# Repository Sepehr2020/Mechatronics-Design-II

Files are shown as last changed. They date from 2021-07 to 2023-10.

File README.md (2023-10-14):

# Mechatronics-Design-II

Course Description:
Interweaves mechanisms, electronics, sensors, and control strategies with software and information technology to examine the demands and ideas of customers and find the most efficient, cost-effective method to transform their goals into successful commercial products. Most of the term is devoted to a significant design project in which student groups work independently and competitively, applying the design process to a project goal set by the faculty coordinator.

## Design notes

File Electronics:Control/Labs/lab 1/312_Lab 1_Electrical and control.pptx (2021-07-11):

## MSE 312: MECHATRONICS DESIGN II Electronics/Control Lab 1 Introduction to Simscape Electrical

Sepehr Rezvani | 301291960
Arash Pour-zargar | 301123105
Chad Graham | 301308419
Darwin Chang | 301315054

## PART B: CREATING A SIMPLE DC MOTOR MODEL

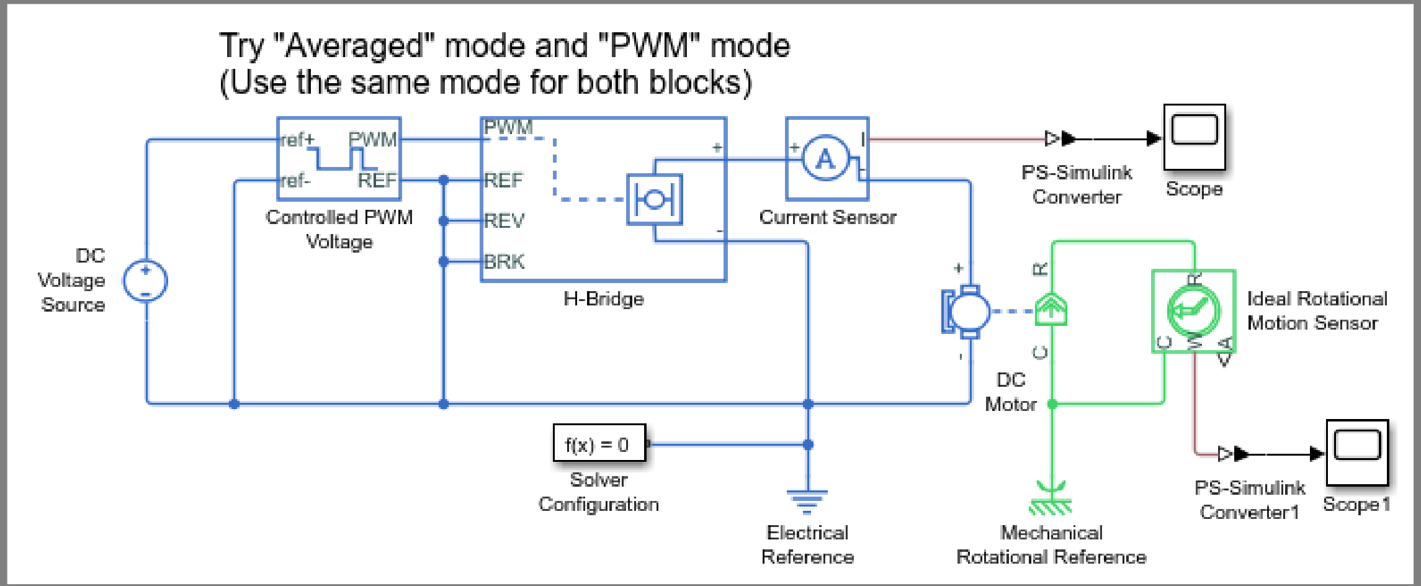
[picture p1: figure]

- Overall DC Motor Layout
- This picture was replicated in Simscape Electrical

## PART B Results

| Left | Right
Top | Averaged Current | Averaged RPM
Bottom | PWM Current | PWM RPM

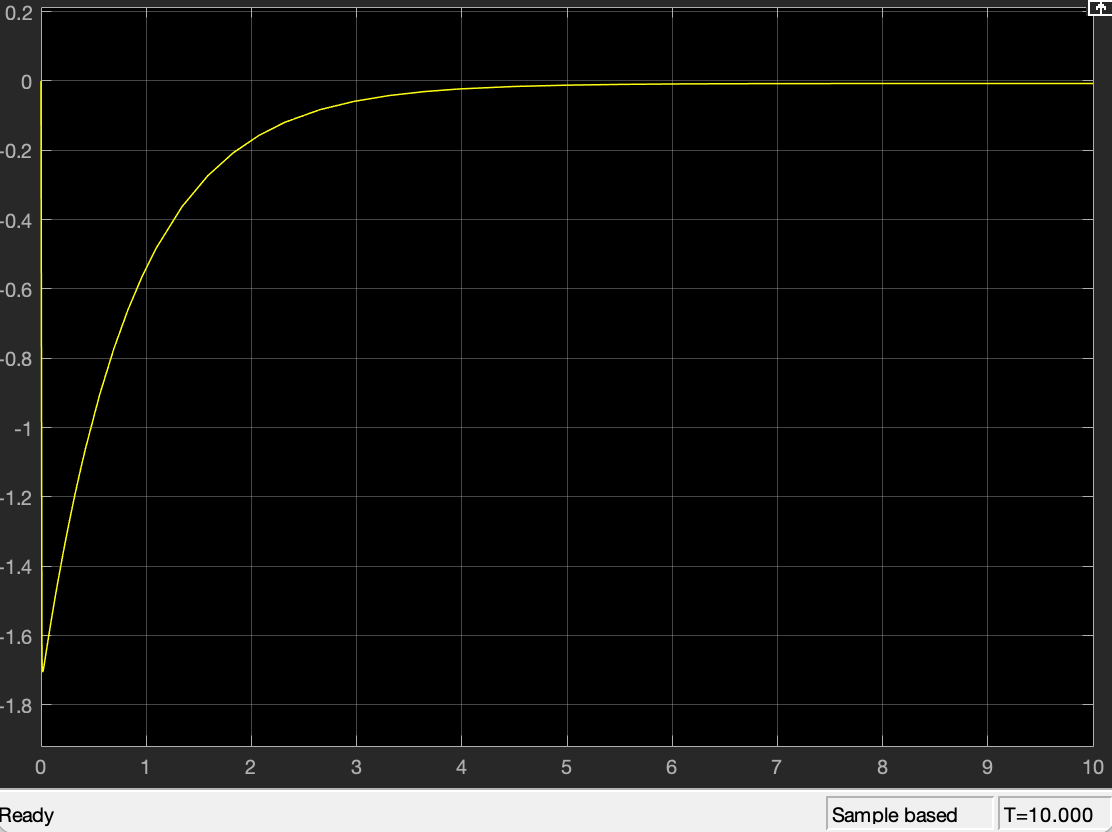
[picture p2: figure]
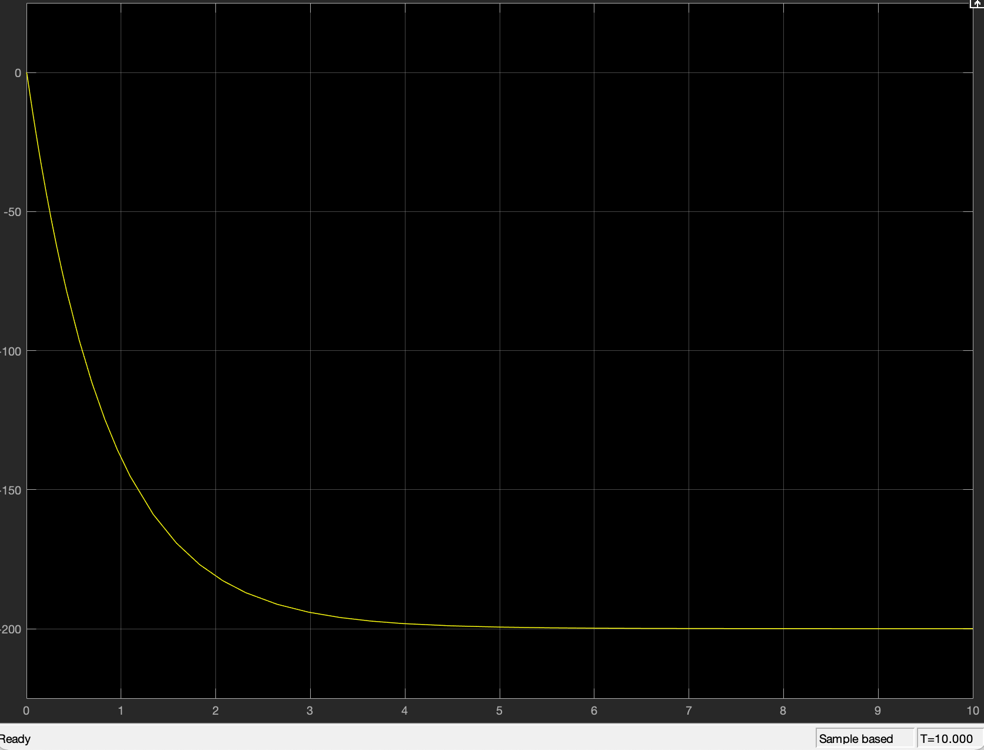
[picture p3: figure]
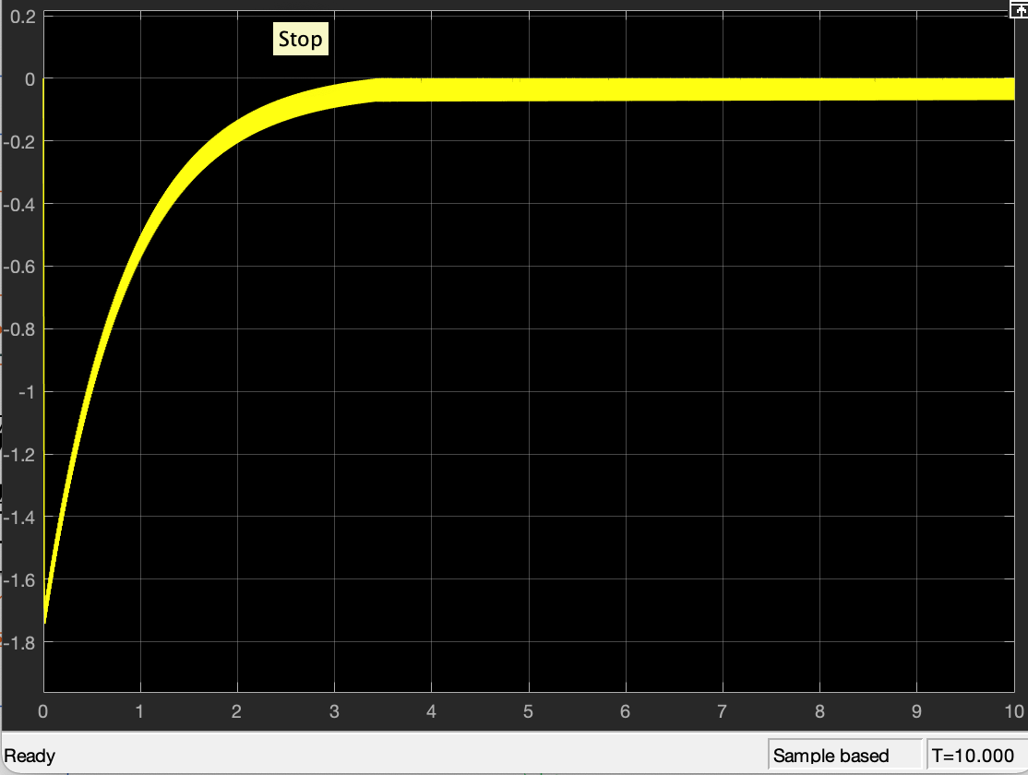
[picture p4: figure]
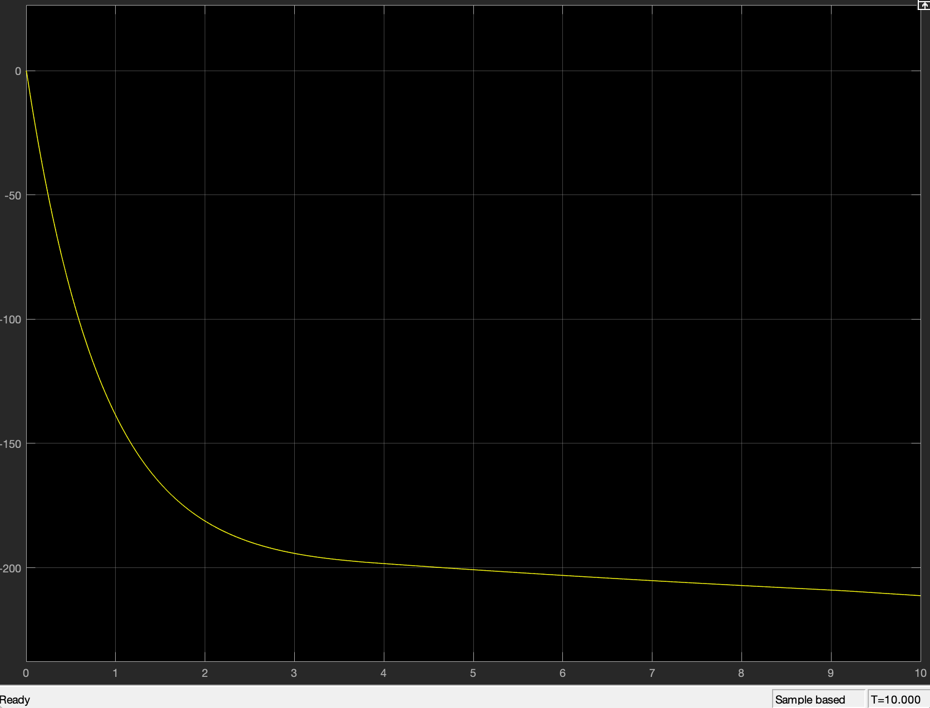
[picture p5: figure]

## ACTIVITY FOR LAB 1

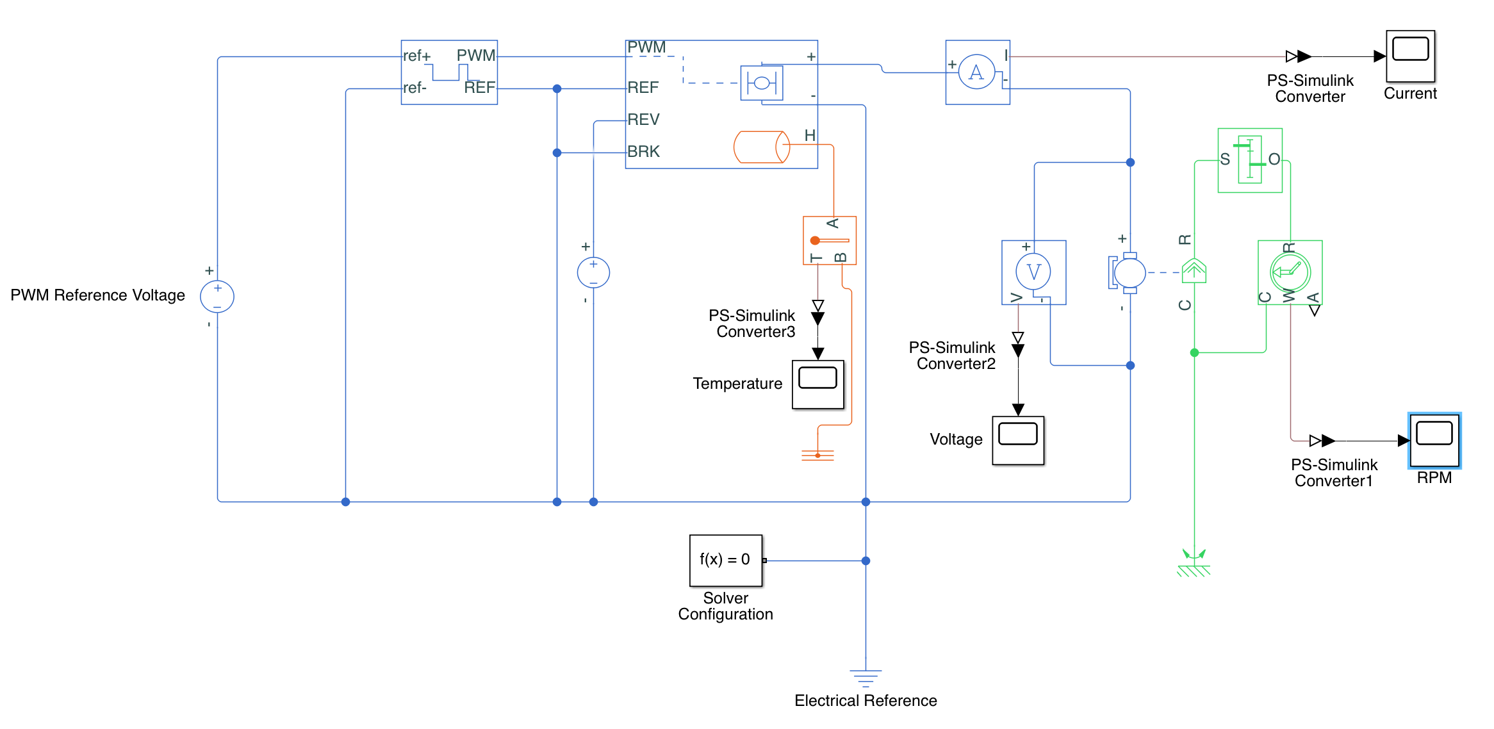
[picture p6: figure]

## ACTIVITY FOR LAB 1

- As seen on the previous page, this design is similar and based on Part B Simscape design
- Here are some additional components added and their purpose:
  - Thermal Port: The Orange section on the H-bridge → To monitor temperature of H-bridge as current goes through.
  - Temperature sensor → connected to scope from one side, and the Thermal Port from the other, to monitor temperature graph of the H-bridge as simulation completes.
  - Voltage Source: In the middle, connected to REV (on H-bridge) and ground → to change normal performance of H-bridge which acts as a diode
(AKA bidirectional requirement).
  - Gear Box → To change Speed/Torque provided by the DC motor.

## Questions

- Are our approaches correct?
  - Reversing the direction of DC Motor other than creating DC voltage source into REV Port
    - Is it possible to get it as an input signal for the REV port
  - Gearbox for Gear
    - How should we approach to measuring torque of the DC Motor
  - Is there a different way to measure power dissipation?
    - Current Method is just through temperature change in the Temperature Scope

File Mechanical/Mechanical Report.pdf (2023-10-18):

## MSE 312: Mechatronics Design II

## Summer 2021

# Project Type Selected:

# Design of a throwing arm

# Brief Mechanical Design Report

Prepared by: Long March

Students Name | Student ID
Arash Pour-zargar | 301123105
Chad Graham | 301308419
Darwin Chang | 301315054
Sepehr Rezvani | 301291960

Submission date: June 21st, 2021

Table of Contents

1 Introduction | 5
2 Design Criteria | 5
3 Proposed Concepts | 6
3.1 Design I - Tennis Ball Launcher | 6
Figure 1: Tennis Ball Launcher | 6
3.2 Design II - Catapult Arm | 7
Figure 2: Catapult Launcher | 7
3.3 Design III - Lacrosse Ball Launcher | 8
Figure 3: Lacrosse Ball Launcher | 8
4 Analytical Calculations | 9
4.2 Structural (Stiffness and Deflection) | 9
4.2.1 Design I | 9
Figure 4: Forces and geometry at the contact between the ball and the rollers during
pulling the ball in between the rollers. [1] | 9
Figure 5: Forces and geometry at the contact between the ball and the rollers [1] 10
4.2.2 Design II | 11
4.2.3 Design III | 11
Figure 6: Static study of support system generate through Solidworks simulation | 12
4.3 Dynamic (Inertia and Kinematics) | 13
4.3.1 Design I | 13
Figure 7: Projectile Motion Diagram | 13
4.3.2 Design II | 14
4.3.3 Design III | 14
5 Mechanical Design Analysis | 16
5.1 Finite Element Analysis | 16
5.1.1 Design I | 16
Figure 9: Design I Force Setup | 16
Table 10: Design I Results Summary | 16
5.1.2 Design II | 17
5.1.3 Design III | 18
Figure 12: FEA analysis Results | 19
5.2 Simulation & Validation | 20

Lab 2: Results | 20
Figure 13: Results Obtained from lab 2 | 20
6 Manufacturing | 21
6.1 Bill of Materials | 21
6.1.1 Design I | 21
Figure 14: Bill of Materials for Design I | 21
6.1.2 Design II | 22
6.1.3 Design II | 23
Figure 16: Bill of Materials for Design III | 23
6.2 Material Selection | 23
6.2.1 Design I | 23
6.2.2 Design II | 23
6.2.3 Design III | 24
6.3 Fabrication Methods | 24
6.3.1 Design I | 24
6.3.2 Design II | 24
6.3.3 Design III | 25
7 Decision Matrix | 26
8 Member Contributions | 27
9 References | 28
10 Appendices | 29
Appendix A: Analytic Calculations | 29
Kinematics of Design I: | 31
Energy Loss | 31
BOM and Cost Breakdown | 32
Design I | 32
Design III: | 37
BOM and Cost Breakdown | 38
Appendix B: Finite Element Analysis: | 39
Design I: | 39
Figure X: Design I Strain Heat map | 39
Figure X: Design I Deflection Heat Map | 40
Figure X: Design I Von Mises Stress Heat Map | 40
Figure X: Design I Force Setup | 40

Design III: | 42
Figure X: Design III Strain | 42
Figure X: Design III Safety Factor | 42
Figure X: Design III Von Mises Stress Heat Map | 43
Figure X: Design III Safety factor 2 | 43
Figure X: Design III Deflection | 43
Appendix C: Simulink/Simscape Models | 45
Appendix D: Detailed Drawing | 50
Appendix E: Lab 2 Code for Hand Calculations, Model, and Simulation | 51

### 1 Introduction

This report outlines the potential conceptual design along with the Mechanical design of a

throwing arm mechanism. Each conceptual design is analyzed and verified to investigate its

performance in its deflection, stiffness, stress, strain, and inertia. Firstly each member has developed

a couple of conceptual designs individually and then all the concepts are shared between all team

members. The pros and cons of each concept are investigated and checked by all team members to

finally come up with three potential final concepts. Finally, the selected conceptual design are

compared using a decision matrix to clarify the priority of each design in our team. The next step was

to design the selected concept using the CAD tool which in our case the software is Solidworks.

Mechanical design and detailed design in Solidworks are performed to determine detailed

information about our selected design. Some of the problems in conceptual design are improved in

this section. For example, we have improved the joint and connections in the Mechanical design to

have only one degree of freedom since it was the requirement of the project. Another example would

be decreasing the length of one of the links in order to decrease the weight of the system and have a

more optimized detailed design for this project. The next step was to determine the stress, strain, and

displacement of the arm using finite element analysis known as FEA in Solidworks .therefore we

imported the CAD model into the simulation section in Solidworks and clarified the fixed point, forces

on the arm, and a proper mesh for the arm. Then we ran the system to see the result of our

mechanical design with the specifications ball in the throwing arm system. Also, a Bill Of Material

known as BOM is added to the CAD model for the next steps in the design. Lastly, a MATLAB/Simulink

model was created for the throwing arm system to analyze the motion of the inertia and the motion

of the throwing arm system. In the following sections, we will explain all the details in a proper

sequence.

### 2 Design Criteria

For this project, our team will be focused on the functional requirements of the end product,

and non-functional aspects will have a lower priority. Our group will use a combination of

Human-Centered Design and Design Thinking. At the end of this semester, professors, who are

considered our clients, will test our products through random target locations on test day and it is imperative that the system meets the design requirements discussed in the project

description.

### 3 Proposed Concepts

3.1 Design I - Tennis Ball Launcher

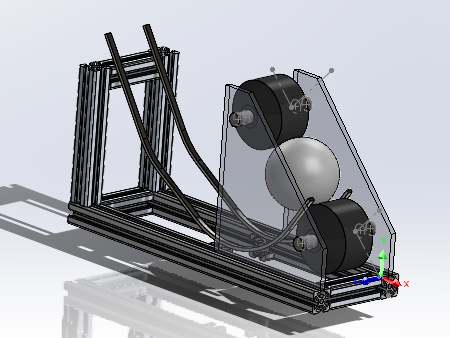
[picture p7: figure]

Figure 1: Tennis Ball Launcher

The first proposed design was a tennis ball or batting cage-style ball launcher. The system will

have the ball rolling down an inclined slope, landing in the launch area. In this area, two wheels

spinning would pull and squeeze the ball and propel it to the desired position. Due to the fixed

launch angle and start position, the only input variable that would need to change is the angular

velocity of the rollers. To protect the motor, and to increase torque a simple gearbox would be

chosen to apply the propulsion to each roller at the same angular velocity.

3.2 Design II - Catapult Arm

Figure 2: Catapult Launcher

The second proposed conceptual design was inspired by a catapult distance. This design will

have the ball at the end of the arm in a bowl-like part. The important point about this

conceptual design is that it is designed to be modular. What it means by modular is that the

middle link and the bowl part are flexible and it can be reshaped and resized in order to have an

optimized result. This conceptual design has 1 degree of freedom in the middle link to rotate

this link in a way that it can provide proper acceleration to throw the ball. The DC motor is

considered to be added at the bottom of this design and the rotary torque is transferred to the

shaft using a belt. The main reason behind that is to have the COM(Centre of Mass) of the

system as low as possible to have a stable system while throwing the ball. This mechanical

design can be controlled using an encoder for the DC motor to provide the proper angle and

acceleration for throwing the ball in order to reach the goal position. Depending on the power

and ratio that is needed in this mechanical design we can use a gearbox system to have a proper

input to the throwing arm.

3.3 Design III - Lacrosse Ball Launcher

The third design is partly inspired by the medieval trebuchet. A DC motor, represented by the

black box, is connected to the side of the throwing arm via a rope. Once the motor starts

rotating, it will pull the rope downwards, causing the arm to rotate, and launch the ball at the

end of its rotation. Similarly, another rope connects the other side of the throwing arm to the

screen door once the arm is in a vertical position (end of launch). That causes the screen door

to open and release an additional ball for the second launch. While the arm is rotating back to

its starting position after the first launch, the second ball has been released from ramp 2 and is

rolling on the ground towards ramp 1. Once the throwing arm is back on the ground to the start

position, the ball will backward from ramp 1 and fall at the end of the throwing arm.

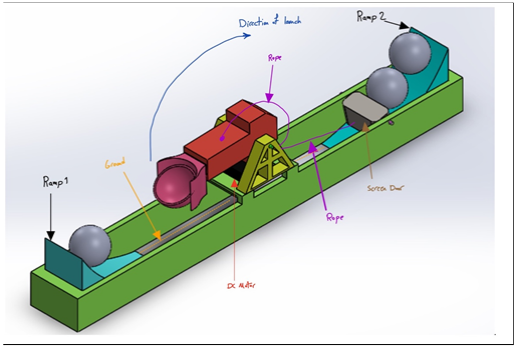
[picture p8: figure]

Figure 3: Lacrosse Ball Launcher

### 4 Analytical Calculations

4.2 Structural (Stiffness and Deflection)

4.2.1 Design I

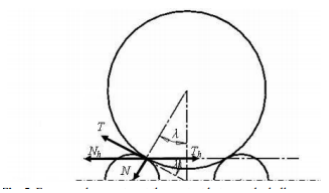
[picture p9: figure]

Figure 4: Forces and geometry at the contact between the ball and the rollers during pulling

the ball in between the rollers. [1]

When the ball is being pulled by the rollers, two main forces appear at the contact points

between the ball and the rollers. These are: the pressure force ‘N’, which is normal to the

contact surface, and the tangent friction force ‘T’ [1].

The relationship between the pressure force and the friction force is proportional to the

coefficient of friction between the materials. This coefficient will be taken from online resources

for approximate materials.

T = µ · N

Figure 5: Forces and geometry at the contact between the ball and the rollers [1]

The condition for throwing the ball away from between the rollers states that the friction force

between the ball and the rollers should be equal or greater than the inertia force of the ball.

The pressure force can be obtained from the definition of Young’s modulus for the ball:

N =

E·s·∆l
2r
Where ‘s’ is the contact area of the ball under compression. The pressure force and tangent

force were determined to be 113.1N and 82.56N respectively. See Appendix A for calculations.

Thus the maximum external load on the system is 113.1N distributed onto the drive shaft. This

force will be used for bending moment calculations performed on the motor drive shaft to

ensure it is within the specifications.

4.2.2 Design II

The first step in static analysis is to have FBD of the system therefore we have added FBD of our

system in the Appendix with all forces on the throwing arm. Then we have used a second

Newton’s law to calculate forces in the joint.

4.2.3 Design III

Two “Arm_support” parts as shown in the following figure must balance out forces and

moments against the rotating arm. Static equations, free body diagrams and detailed

calculations of results

are included in Appendix A.

Figure 6: Static study of support system generate through Solidworks simulation

4.3 Dynamic (Inertia and Kinematics)

4.3.1 Design I

The system will consider the start position of the ball to be between the two rollers at a fixed

angle of 45 degrees to optimize trajectory. The input into the plant will be the angular velocity

of the rollers.

During the throw, the ball takes some energy from the rollers while going through them. This

decreases the rotational speeds of the rollers. To analyze this further we must consider the

kinetic energy of the rollers at the time of the ball being thrown. We came to the conclusion

that the initial angular velocity must be adjusted to the following. See Appendix A for the

breakdown.

ω0 = ω +

1
2

I

ballω

2

Now that the input has been determined, the landing position of the ball can be determined

using standard projectile motion calculations.

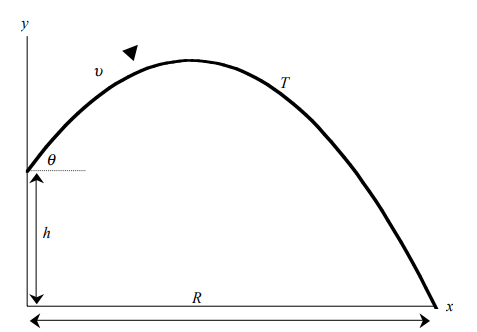
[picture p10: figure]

Figure 7: Projectile Motion Diagram

4.3.2 Design II

The second step is to calculate the moment of inertia for the arm using the following equation

Then we would be able to calculate all the Mechanical design parameters which are added in a

table in the appendix.

For the other part which is the base of the catapult design we only need a static analysis to

make sure the base will be stable during the throwing period using the following equation. The

corresponding image is added in the appendix

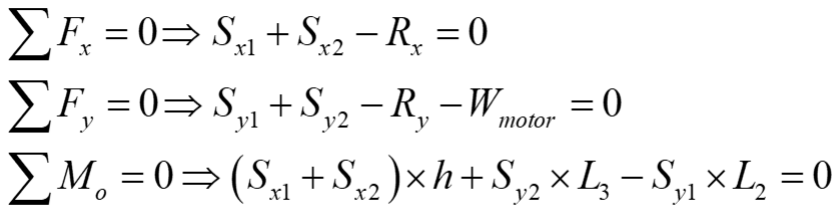
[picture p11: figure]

4.3.3 Design III

As shown in the following figure, the Throwing arm’s center of mass is away from the rotating

rod. Therefore, to balance forces and moments acting on the supports, the arm must be

designed in a way that is more dense on the right (in red). The reason for this design is to

balance negative torque, help with rotations counter torque, and minimize the power required

from the DC motor.

Figure 8: Mass distribution of the arm

This logic can also be seen in trebuchet design in the following figure. Instead of m1 in

trebuchet, our design is denser on the right side.

### 5 Mechanical Design Analysis

5.1 Finite Element Analysis

5.1.1 Design I

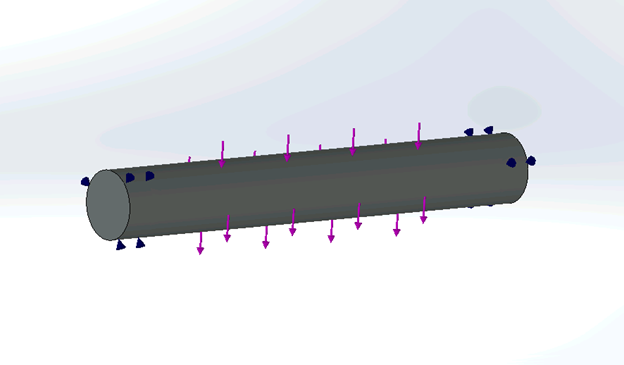
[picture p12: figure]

Figure 9: Design I Force Setup

A FEA analysis was performed on the drive shaft of the proposed tennis ball launcher concept

and the heat maps can be found in Appendix B. Bearing fixtures were set up on the edge of

each shaft to imitate its final design. The force was applied perpendicular to the axis of the shaft

to mimic the friction force applied from the ball. The summary table can be seen below.

Table 10: Design I Results Summary

Parameter | Simulated Results | Analytical Solution
Displacement/Deflection | 0.9104mm | 1.66mm
Yield Strength | 2.206x10^8 Pa | N/A
Strain | 3.401 x 10^-04 | N/A

The analytical and simulated results were comparable for the deflection of the drive shaft as

shown in the table above. The next following section will discuss material selection to ensure

the concept will perform as intended.

5.1.2 Design II

For the finite element analysis, I have imported the CAD model into the simulation section of

the Solidworks in order to analyze displacement, stress, and strain of the throwing arm to make

sure the throwing arm can tolerate the weight of the ball and other forces on it. Thus the results

are added below

Figure 11a: FEA of the beam

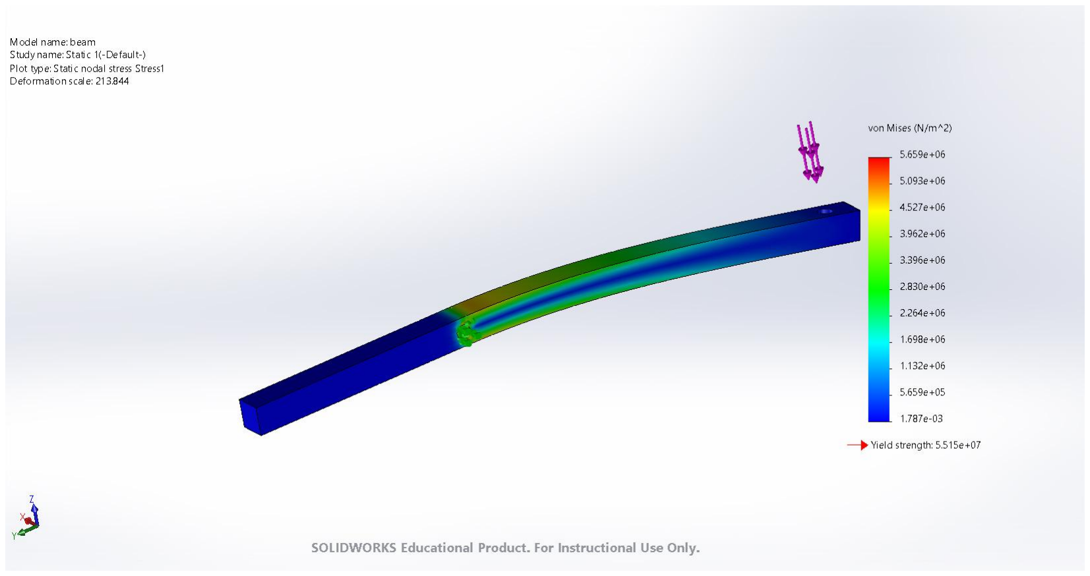
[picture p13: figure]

Figure 11b: FEA of the beam

5.1.3 Design III

After performing FEA analysis in Solidworks for this design, results for stress, deflection, and

strain are calculated and presented in the following table. For a more detailed analysis of figures

refer to Appendix B under “Design III”.

Name | Type | Min | Max
Stress | VON: von Mises Stress | 6.425e+00N/m^2 | 4.204e+04N/m^2
Displacement | URES: Resultant Displacement | 0.000e+00mm | 1.308e-05mm
Strain | ESTRN: Equivalent Strain | 2.640e-10 | 2.620e-07
Factor of Safety1 | Max von Mises Stress | 1.927e+04 | 1.261e+08
Factor of Safety2 | Max von Mises Stress | 1.927e+04 | 1.261e+08

Figure 12: FEA analysis Results

5.2 Simulation & Validation

Assembly files from three designs were exported into Matlab Simscape. Simscape helps with

developing physical models and simulate them. Results from the second lab are presented in

the following table. In addition, codes and figures of our Simscape designs are included in

Appendix D.

Lab 2: Results

| Angular Velocity (After 10 second) | Angular Acceleration (After 10 seconds)
Base Model | -4.53811 | -10.3749
Geometry 2 | 4.7461 | 9.0776
Geometry 3 | -4.5887 | -10.1299
Material (rho) 2 | 4.6073 | 9.9035
Material (rho) 3 | 4.516 | 10.4963
Inertia 3 | 0.7689 | 0.0415
Solver (auto) | 4.5023 | 10.5475
Solver (ode15s and time 0.001s) | 4.5023 | 0.5475
Damping (8e-4) | 4.8418 | 7.8544
Damping(8e-1) | -4.45E-04 | 9.93E-05
Torque (100) | 23.2331 | -15.7428
Torque (1) | 4.4613 | 10.675

Figure 13: Results Obtained from lab 2

### 6 Manufacturing

6.1 Bill of Materials

6.1.1 Design I

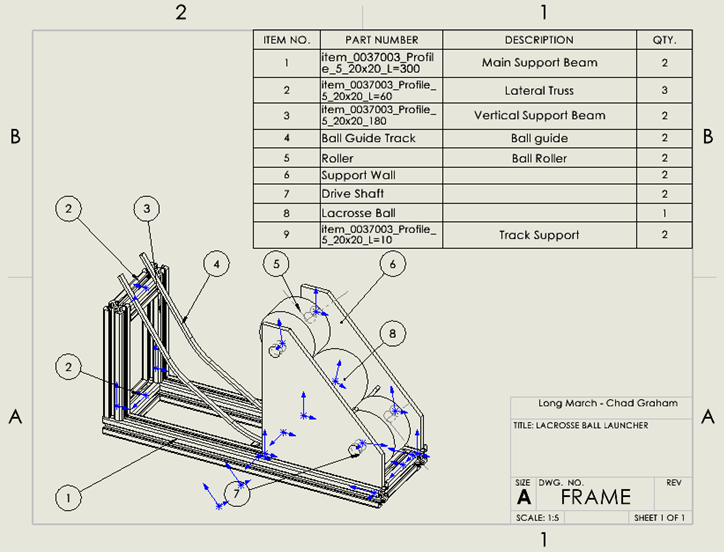
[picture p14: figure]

Figure 14: Bill of Materials for Design I

6.1.2 Design II

Figure 15: Bill of Materials of Catapult Arm

6.1.3 Design II

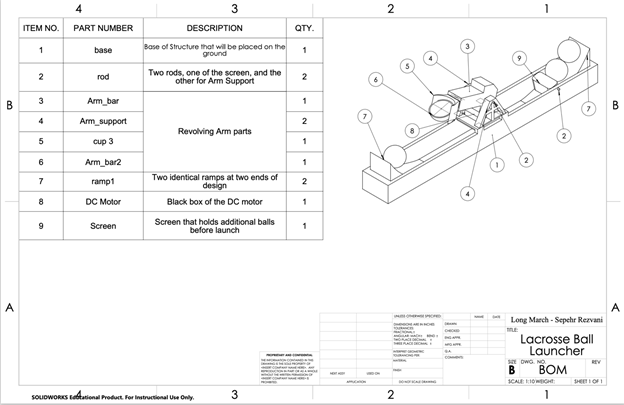
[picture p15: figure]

Figure 16: Bill of Materials for Design III

6.2 Material Selection

6.2.1 Design I

The main structure will be constructed from aluminum extrusion due to its incredible yield

strength, availability, and affordability. The Ball Guide Track is made out of stainless steel. The

driveshaft was selected to be made out of 1045 Cold Drawn Steel due to its corrosion resistance

and superior yield strength. The rollers will be made out of high-density rubber to maintain a

high coefficient of friction with the lacrosse ball to minimize slip.

6.2.2 Design II

There are many choices for selecting the proper material for the components of the second

design. First of all, we have tried to use one material for the whole system in order to reduce the cost of manufacturing and maintenance of the throwing arm project. Thus using static

analysis results which are added in the appendix we have decided to use aluminum alloy 6061

as the main material for manufacturing the second design. The approximate cost of the design

according to the quantity of the material used is around $200-$250 dollars

6.2.3 Design III

As shown in table (Design III) in Appendix A under "BOM and Cost Breakdown", the materials

selected are based on the purpose of parts in the design. For example, “Titanium Ti-8Mn,

Annealed” is used for the “Arm_support” part due to the high stress applied to this part. For

other parts like ramps, where very little load is applied, simpler and cheaper materials were

selected. Another factor considered for the material selected is their availability in the

Solidworks database, in some special instances, better materials could be selected if they were

available in Solidworks.

6.3 Fabrication Methods

6.3.1 Design I

This iteration was purposely designed for ease of manufacturing in mind. Each material is

readily available from local suppliers such as Proax, McMaster Carr, and others. Basic hand tools

will be used to fabricate the simple frame structure and the drive shaft can be ordered from

McMaster Carr to fit the design. Extrusion can be cut with a simple saw and constructed with

nuts and bolts.

6.3.2 Design II

Depending on the material that we select for the second design we have different options for

manufacturing the components for example if the material is selected to be PLA then the

manufacturing method would be 3D printing. For this project if the material is aluminium alloy

the manufacturing method is selected to be CNC machining however we have an option to

move forward with 3D printing method for the Cap in the second design thus since the shape of

this component would cost more using CNC machining

6.3.3 Design III

As mentioned in the previous section, materials were selected based on their importance and

cost. Referring to Appendix A, these main portions of our budget would be allocated to the

main arm and its supports. All materials are available and can be purchased with our limited

budget.

### 7 Decision Matrix

A weighted objective chart (WOC ) is used as a means of comparing various alternatives by

ranking them based on a list of criteria . The weighted table work is that the user pre-rank the

important stuff each of the comparison criteria in advance then ranks each design option based

on how well it fulfills each of the criteria. The list of criteria for our project is shown below:

In the following, different values are assigned to each score so that the higher score has a better

advantage to our design for example if the cost of the design is less then its score would be

higher. The list of criteria with the corresponding values is shown below.

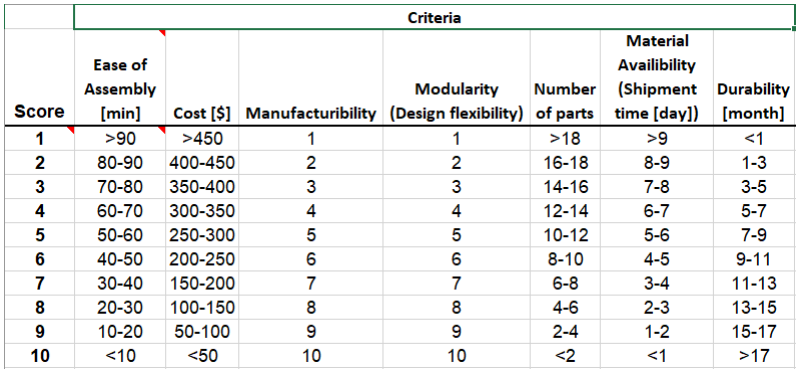
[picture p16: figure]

Figure 17: Decision Matrix

Finally, the criteria and the corresponding score are finalized and now we have assigned a

weight to each criterion .it should be noted that the total weight should be 100%. Then we have

compared all three concepts using a score for each criterion and added a value

(is equal to score *weight ) for each criteria. Finally, the accumulated values are compared in

the following table

Figure 18: Selected Design

Ultimately this led our team to select Design III as our mechanical concept. It yielded the

highest overall score by a significant amount. Though selected, the design will continue to be

iterated and optimized to properly integrate the motor and drive system.

### 8 Member Contributions

Chad Graham - Design I (Mechanical design, analytical calculations, FEA, BOM, material

selection, cost breakdown. report, etc.), report format layout, grammar correction, and

organization.

Arash Pour-Zargar- completed design 2 on the FBD design as well as FEA, material selection,

BOM, and creation of the report template as well as the decision matrix

Sepehr Rezvani - Design III and report+formatting: Including Solidworks parts, drawings, and

one final assembly file. FEA was done on Throwing Arm support, BOM and final cost estimation

was completed as well.

Darwin Chang - Report. Ensuring compatibility and Importing of the Solidworks model into the

Simulink/simscape models to be able to create the Model for the three designs. Simulated the models and fixed model errors present in the importing process. Obtained the results for Lab 2

shown in appendices E. Report Grammar, and Formatting

### 9 References

[1] K. WÓJCICKI, K. PUCIŁOWSKI, and Z. KULESZA, “Mathematical Analysis for a New Tennis Ball

Launcher,” Acta Mechanica et Automatica, vol. 5, no. 4, pp. 110–119, 2011.

[2] | “Polymer | Properties | Database,” | Rubber | Elasticity. | [Online]. | Available:
https://polymerdatabase.com/polymer%20physics/RubberElasticity.html. | [Accessed:

20-Jun-2021].

3] K. WÓJCICKI, K. PUCIŁOWSKI, and Z. KULESZA, “Mathematical Analysis for a New Tennis Ball

Launcher,” Acta Mechanica et Automatica, vol. 5, no. 4, pp. 110–119, 2011.

L. L. C. Engineers Edge, “Coefficient of Friction Equation and Table Chart - Engineers Edge,”
Engineersedge.com. | [Online]. | Available:

https://www.engineersedge.com/coeffients_of_friction.htm. [Accessed: 20-Jun-2021].

“Polymer | Properties | Database,” | Rubber | Elasticity. | [Online]. | Available:
https://polymerdatabase.com/polymer%20physics/RubberElasticity.html. | [Accessed:

20-Jun-2021].

### 10 Appendices

Appendix A: Analytic Calculations

Load Validation Design I:

N =

E·s·∆l
2r =

(4.0×10

6
Pa)( 5.94×10

−4m

2
)(0.003m)
2·(0.0315m) | = 113. 1N

S = Contact area during deformation
s = 2 · π · r · ℎ = 2 · π · (0. 0315m) · (0. 030m) = 5. 94 × 10⁻⁴
m

2

The area of deformation was determined by considering the surface area of a dome with the

height equal to one half of the deformation height (3mm).

△l = deformation height

The deformation height is determined from the spacing between the two rollers. The rollers

were separated by the diameter of the ball minus 6 mm to ensure a constant pressure is

maintained.

R = radius of the ball

E = Young’s Modulus

Since the material of a lacrosse ball is not consistent, vulcanized rubber (a common component

in lacrosse balls) was selected to represent the material properties. 4.0MPa was determined for

our calculations[CHAD 2].

The coefficient of friction was found from an online resource to be 0.73[CHAD 3].

T = µ · N = (0. 73)(113. 1N) = 82. 561N

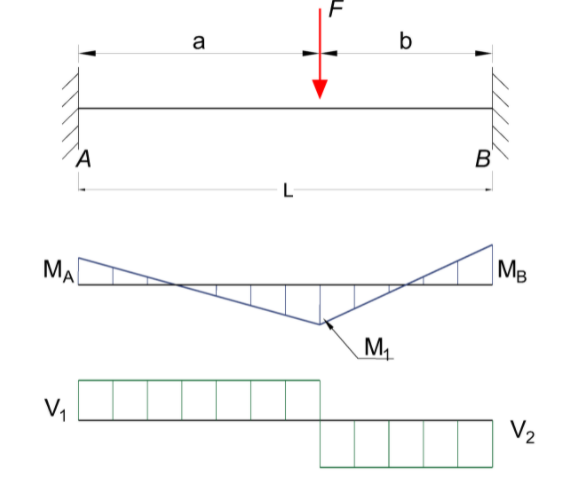
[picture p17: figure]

Figure 19: Bending Moments Graph

The moment of the fixed ends of the beam was determined as follows.

M

A = M

B =

−Fa

3

L

2 =

(113N)(0.0426)

3

(0.0852)

2 = 0. 00120345Nm

The moment of the center of the beam was determined as follows.

M =

2·F·a
L

3 =

2·(113)(0.0426)
(0.0852)

3 = 1. 20345×10 − 5Nm

The deflection was calculated for the top of the shaft at its extremity as follows.

δ

beam =

F·a

6

3·L

3
·E·I

= 1. 66311386×10 − 4m

Kinematics of Design I:

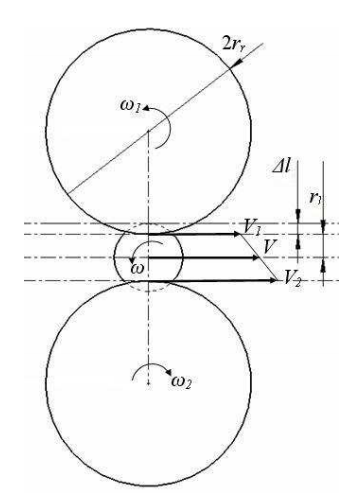
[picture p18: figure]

Figure 20: Tennis Ball Launcher Cross Section

V =

V

1 +V
2
2 ϖ · r

roller =

V

2−V
1
2

V =

(ω1+ω2

)·r

2

Energy Loss

Consider the kinetic energy of the rollers at the moment the ball is thrown.

∆E = E

1 − E

2 =

1
2
- I
roller

[(ω1

2
+ ω2

2
) − (ω10

2
+ ω20

2
)]
Where; | I

roller =

1
2 mr

2

For the ball it can be assumed that its initial kinetic energy is zero, while the final energy, in this

case immediately after the throw, depends on its linear and rotational speeds of the rollers.

Since both rollers will have the same angular velocity the angular velocity of the ball can be

assumed to be zero.

Thus; | ∆E =

1
2
- mV

2
+

1
2

I

ballω

2

Where; | I

ball =

2
3 mr

2

Therefore the initial kinetic energy of the plant required to launch the ball using the equations

above can be shown as:

E =

1
2

I
roller

(ω1

2
+ ω2

2
) +

1
2 mV

2
+

1
2

I
ball
Making the assumption that angular velocity before and after the launch are the same:

ω10

ω20

≃

ω1

ω2

Then, the initial rotational speeds of the rollers, needed to throw the ball with the required

linear and rotational velocities can be calculated, as:

ω0 = ω +

1
2

I

ballω

2

BOM and Cost Breakdown

Figure 21: Cost Breakdown of Tennis Ball Launcher

Design I

Design III:

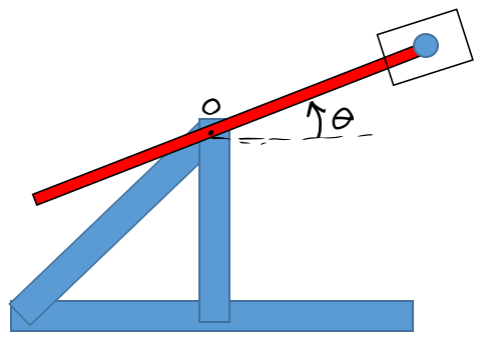
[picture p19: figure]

Figure 22: Cross Section of Catapult

The first step for static analysis is to have FBD of the Catapult throwing mechanism. I have

added the FBD as follows

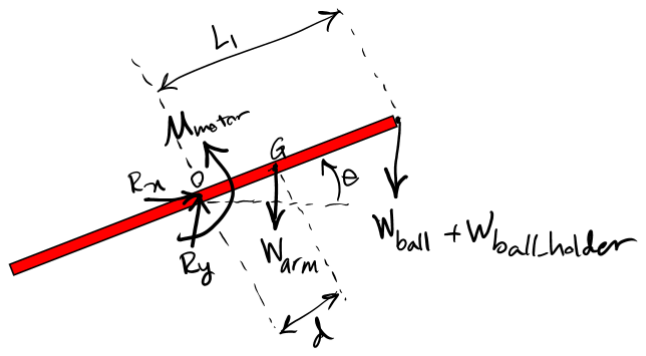
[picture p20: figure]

Figure 23: FBD Diagram of throwing mecahnism

Figure 24: FBD fo the A frame

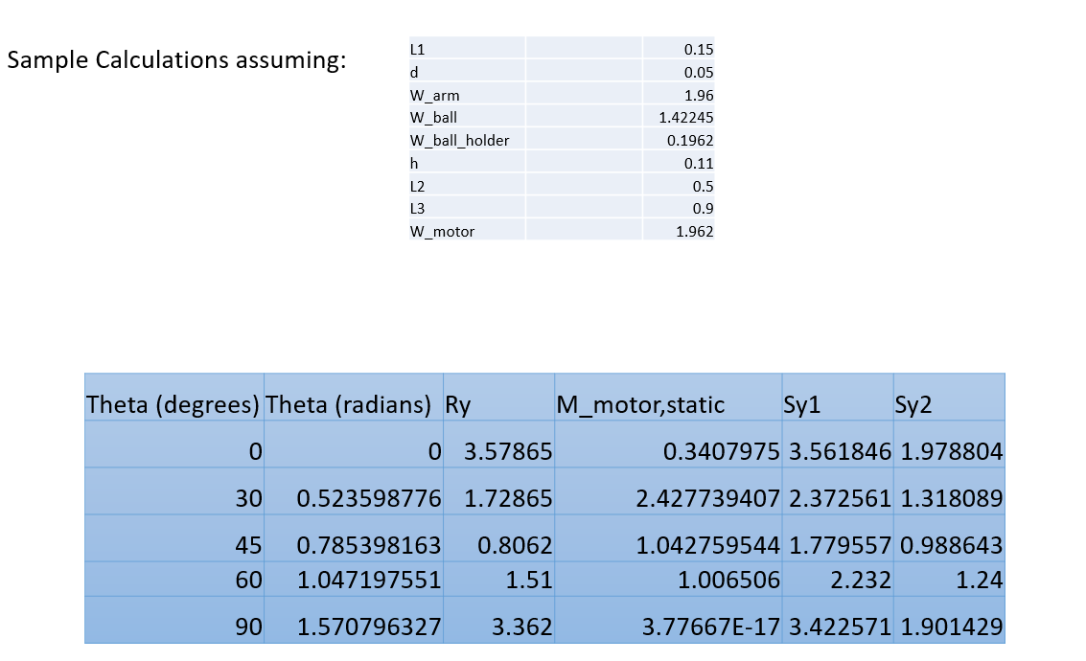
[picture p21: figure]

Figure 25: Sample Calculations

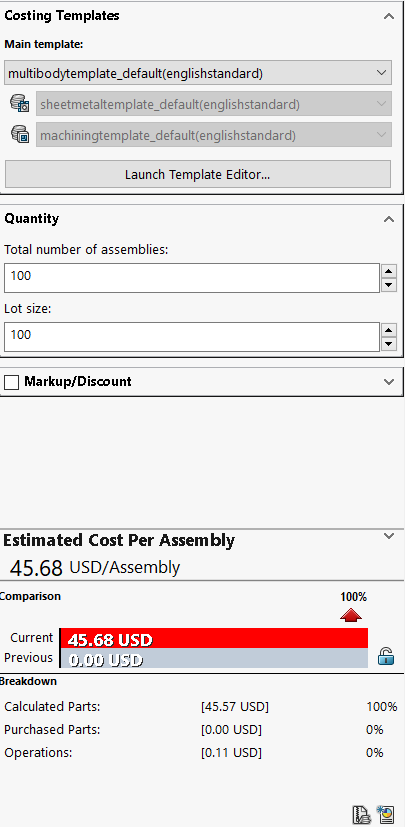
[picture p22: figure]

Figure 26: Cost Breakdown of Catapult System

Design III:

Figure 27: FBD and calculations of Design 3

BOM and Cost Breakdown

Appendix B: Finite Element Analysis:

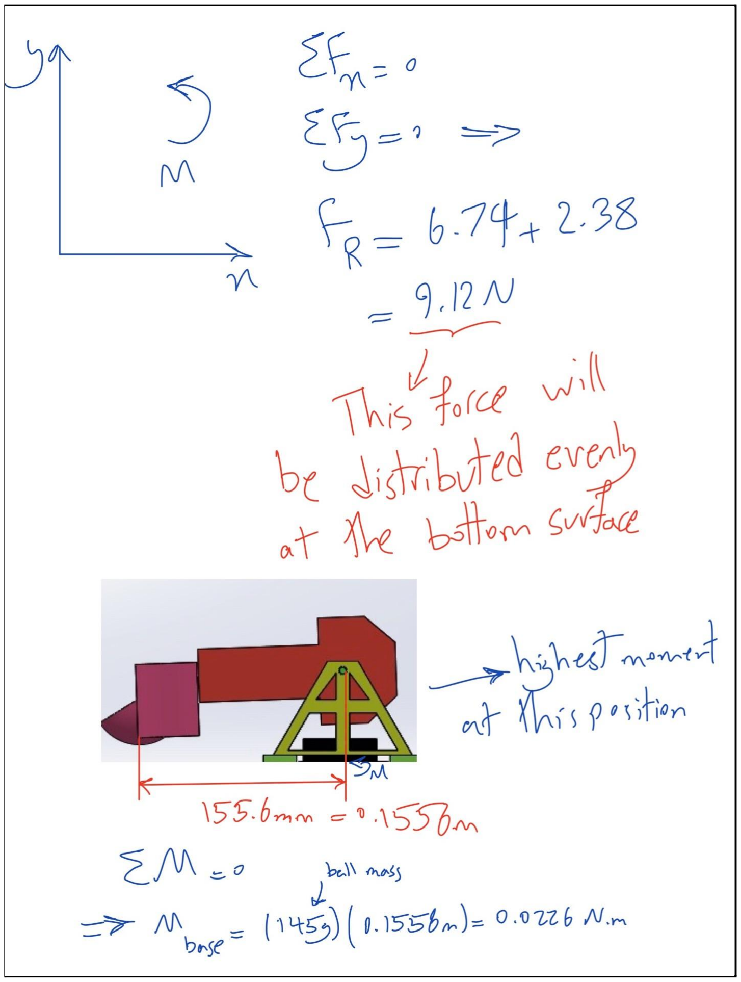
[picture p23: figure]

Figure 27: FBD and calculations of Design 3 cont.

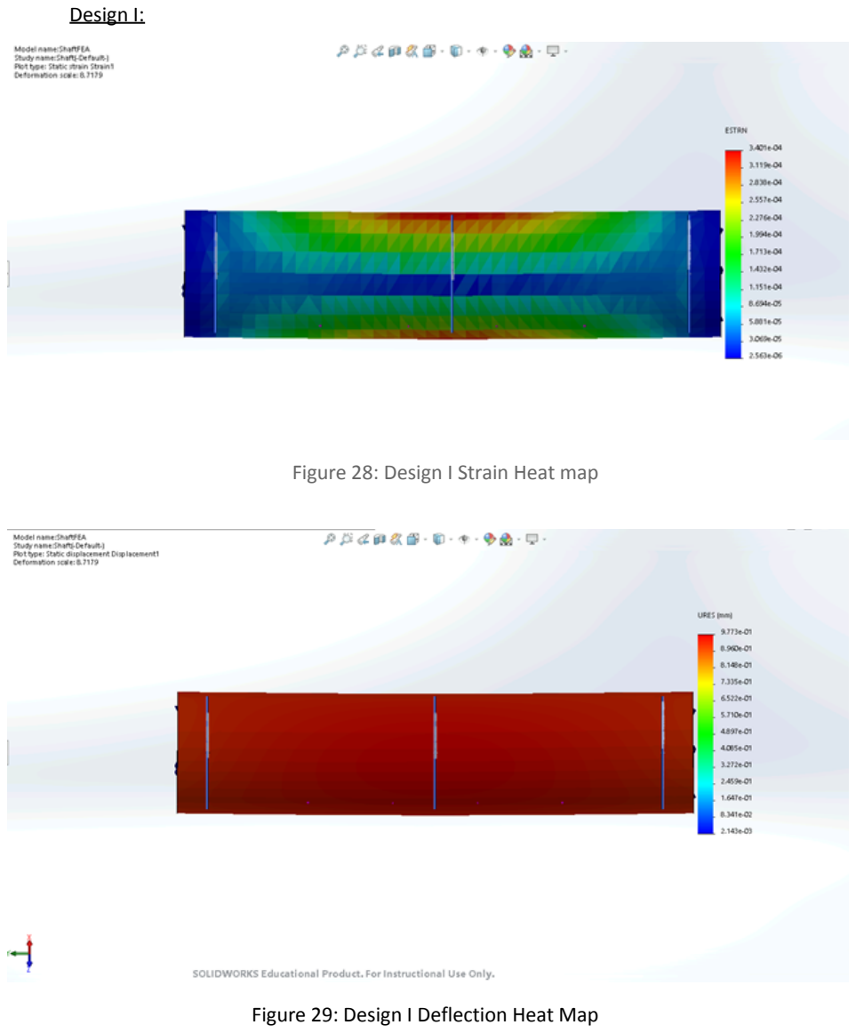
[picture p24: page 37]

Design I:

Figure 28: Design I Strain Heat map

Figure 29: Design I Deflection Heat Map

Figure 30: Design I Von Mises Stress Heat Map

Figure 31: Design I Force Setup

Design III:


Figure 32: Design III Strain

Figure 33: Design III Safety Factor


Figure 34: Design III Von Mises Stress Heat Map

Figure 35: Design III Safety factor 2

Figure 36: Design III Deflection


Appendix C: Simulink/Simscape Models

Model 1:

Figure 37: Simulink Model for Design 1: Tennis Ball Launcher

Model 2: Catapult Arm

Figure 38: Simulink Model for Design 2: Catapult Launcher

Model 3:


Figure 39: Simulink Model for Design 3: Lacrosse Ball Launcher

Appendix D: Detailed Drawing


Figure 40 - Drawing of Design III Assembly Signed by Group Members

Appendix E: Lab 2 Code for Hand Calculations, Model, and Simulation

close all

clc

% Calculations for lab 2

rho = 2700;

length=1;

width=0.10;

thickness=0.10;

volume = length * width * thickness;

mass = rho * volume;

inertia_cent = (1/12)*(length^2 * width^2);

inertia = inertia_cent + (mass)*(length/2)^2;

% assumming start from rest, and bar is horizontal

gravity = 9.81;

energy=mass*gravity*sin(pi/2)*length;

velocity = sqrt((energy*2)/mass); %from kinematic energy

ang_velocity_90=velocity*length/2;

disp(ang_velocity_90)

ang_velocity_180=0; % returns to starting height

disp(ang_velocity_180)

ang_velocity_270=-ang_velocity_90; % same as 90 but opposite direction

disp(ang_velocity_270)

ang_velocity_360=0; % back to original direciton

disp(ang_velocity_360)

figure;

hold on;

plot(out.w);

plot(out.a);

legend('w', 'a')

disp(out.w(end));

disp(out.a(end));

Figure 41: Code for Lab 2 Calculations


Figure 42: Simulink Model for Lab 2, pendulum arm

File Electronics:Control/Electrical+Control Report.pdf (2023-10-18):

## MSE 312: Mechatronics Design II

Summer 2021

# Electronic Drive Circuit and Control System Design for a Throwing Robotic Arm:

### Prepared by: Long March

### Submission Date: July 25th

, 2021

Student Name | Student ID
Sepehr Rezvani | 301291960
Chad Graham | 301308419
Arash Pour-zargar | 301123105
Darwin Chang | 301315054

Table of Contents

### Introduction

In this project we develop controllers for a Throwing Robotic Arm, which throws a ball from a

reference point (zero position) to a target point. The target point is in three different ranges,

and the ball must land withing 2cm of the specified location.

In Mechanical portion of this course, Long March developed three mechanical designs in

Solidworks, and integrated them in Simulink for simulation. Once mechanical part the project

was completed, Long March has been focused on designing power electronics drive circuitry for

our electronic system. Additionally, simulations at different levels have been completed as well

in order to validate quality of our electronic system.

While some members have been working on electronics design, other have been working on

the control portion of the project as well. The DC motor (GM8724S009), H-Bridge (TB6568KQ)

and other electronics components power the mechanical side of the design. However, control

circuitry is as important as the power systems since the motion of the Throwing Arm must be

fully controlled. Otherwise, the ball cannot successfully leave the arm.

In this report, Long March will demonstrate how to design, test, and validate electronics and

control components of this course. Readers can follow report’s instruction to simulate a similar

project in Matlab/Simulink.

## Part A: Electronics

Electronics Introduction

In this section the design and power interface circuitry for driving a DC motor carrying an

inertial load, in this application our throwing arm. In a real system, a power electronics

interface is necessary since the control/command signals from the microcontroller cannot

provide enough power to drive the motor and the electromagnet.

Motor Selection

Seeing as the desired system is to be electro-mechanical, a suitable motor is to be selected to

propel our ball to its destination. The following criteria will be used to select our motor.

- Must be a DC Brushed motor capable of forward and reverse actuation
- Must be within the 0-12VDC operating range to minimize power
- Must be capable of generating at least 6.004oz*in of torque as calculated to be the

minimum torque to drive our mechanical system.

- Must have a gearbox to reduce strain on motor and increase torque
- Gearbox must be of at least 90% efficiency to minimize power loss.
- Must be affordable to be within project budget.

Figure 1: GM8724S009 DC Gearmotor [1]

The following motor was selected for our system. The GM8724S009 DC servo gear motor is a

DC motor made with Copper-Graphite brushes that has a nominal voltage of 12VDC. It’s gear

ratio of 6.3 and stainless-steel shaft will reduce strain on the motor and provide up to 42 oz*in

of torque to our system [1].


Figure 2: GM8724S009 Torque Speed diagram

In the figure above the vertical green line represents the minimum torque needed to propel the

ball in our system. It is clear it is well within the operating range of our system and still provides

a lot of operating power to propel the ball to the desired positions.

Design Stages of Power Electronics Drive Circuitry

DC Motor Control

Theory

A simple DC motor uses a stationary set of magnets in the stator, and a coil of wire with a

current running through it to generate an electromagnetic field aligned with the center of the

coil. One or more windings of insulated wire are wrapped around the core of the motor to

concentrate the magnetic field.

The windings of insulated wire are connected to a commutator (a rotary electrical switch), that

applies an electrical current to the windings. The commutator allows each armature coil to be

energized in turn, creating a steady rotating force (known as torque) [2].

By nature, applying a positive voltage potential across a motor will rotate the motor forward

and applying a negative voltage potential across the motor will rotate the motor in reverse.

Thus, it is imperative to design a controller that can convert simple control signals into the

desired direction control.


Figure 3: Direction Control of a DC motor

The proposed electrical circuit is a H-Bridge circuit. In general, an H-bridge is a rather simple

circuit, containing four switching elements, with the load at the center, in an H-like

configuration:


Figure 4: H-Bridge Circuit Topology

The switching elements (Q1...Q4) are usually bi-polar or FET transistors, for our application we

are using MOSFETs. The diodes (D1...D4) are called kick-back or snubber diodes. The top-end of

the bridge is connected to a power supply (battery for example) and the bottom-end is

grounded. The operation table can be seen below according to Figure 5.

Table 1: H-Bridge Sequence

Motor Operation | S1 | S2 | S3 | S4
Off | Open | Open | Open | Open
Clockwise | Closed | Open | Open | Closed
Counter-clockwise | Open | Closed | Closed | Open
Invalid | Closed | Closed | Closed | Closed


Figure 5: H-Bridge Circuit

The speed can be controlled using PWM. Changing (modulating) the width of the pulse applied

to the motor can increase/decrease the amount of power provided increasing/decreasing the

motor speed.


Figure 6: PWM Diagram

Implementation

A Toshiba TB6568KQ Full-Bridge DC Motor Driver IC was selected to be our H-Bridge device. The

basic electrical implementation in Simulink can be shown below. This model shows how to use the Controlled PWM Voltage and H-Bridge blocks to control a motor. The DC Motor block uses

manufacturer datasheet parameters found on our H-Bridge and motor datasheets respectively.


Figure 7: Electrical Control Simulink Circuit

To implement direction control, the H-Bridge block by default runs in the forward direction and

if the voltage applied at the ‘REV’ port is larger than a pre-defined voltage, the motor will run in

reverse. Thus, if the voltage is greater than zero volts, 5V is applied to the ‘REV’ port and the

motor is ran CW, if it is less than 5V, 0V is applied to the ‘REV’ port and the motor is turned

CCW.

Figure 8: Simulink Circuit of Direction Control

The simulation was populated with the parameters obtained from the respective datasheet.

This can be found in Appendix: Part A. The simulation results can be found in the sections

below.

Thermal Design for PWM Chip

Using the properties from the TB6568KQ datasheet [4] the selection criteria for a heatsink can

be obtained. The temperature difference between the junction and the ambient depends on

the power dissipation (PD) and the thermal resistance between them as shown in the equation

below. The PD was extracted from the datasheet to be 7.80W. Seeing as the power dissipated

was less than 10W, a passive heatsink was selected.

The thermal resistance between the Chip and the Ambience can be broken down into a pair of

series resistances as shown below.

Combining the two equations listed above and rearranging to solve for the unknown thermal

resistance of the Chip to the Case can be shown as follows where θChipCase was extracted from

the datasheet to be 6°C/W. TChip is a known value for silicon devices to be 150°C.

A rough formula for designing a passive heat sink can be shown below where the area units are

in cm² and the thermal resistance is measured in °C/W.

Applying a 50% safety factory yields an aluminum heat sink area of 37.5cm² .

Simulation Results for Evaluation Power Drive Circuit Operation

Long March has implemented lab 1 design in the project. Many factors such as nonlinearities

and uncertainties from the electrical section can affect the performance of the system. This

section explains how different parameters (e.g. motor or H-bridge values) can change

simulation results. For the electrical simulation, Long March developed the following design to

test electrical components. Shown in the figure below.


Note that this design was modified to integrate into the model, and a PID block was added to

implement PID for the current control of the control project. At the center of this design, we

have a DC motor and H-Bridge that controls the direction of current in the motor. Values are

based on the motor and bridge selected for this project that is with the specification values

included in Appendix A. Controlled PWM block creates the Pulse-Width Modulation voltage

signal across its PWM and REF ports, which are connected to PWM and REF ports of the H-

bridge, respectively.

In this circuit, a step input was used for testing usage to create a predictable desired current.

The purpose of this specific structure was to help us with signal tuning for the controller

project. Further details will be discussed in the portions of the control of the report. Table 4 in

Appendix A shows settings for the Controlled PWM voltage. Note that Output Voltage

Amplitude must match PWM Voltage Amplitude in the H-bridge. Voltage and current sensors

connect to different scopes to help us understand how values change in different parts of the

circuit. For example, figure 10 compares voltages at 4 different stages of the circuit, which are the following: the h-bridge’s REV port voltage, the desired input current to the system, the h-

bridge’s PWM port voltage, and the voltage across the DC motor. These scopes were not

required for lab 1, however, they helped with the analysis of errors

in the integration of our system.


Figure 10 – “rev volt vs. PID output AND PWM voltage vs. motor voltage”

“rev port voltage”, is directly affected by the value obtained from desired input current, and

condition of the switch. For integration portion of the project, the switch was used to change

voltage value entering REV port in the h-bridge to change polarity of the output voltage. This is

how direction of rotation of DC motor is controlled. The following figure shows the input (step)

current vs. actual current. There is a slight overshoot at t=1, and the actual current drops down

to about 1.4A. This error can be fixed by implementing proper PID values, which will be done in

part B.


Figure 11 – Actual vs. Desired Current of the Power Drive Circuit

Another important part of the power drive circuit is position and velocity of the motor, and

they are included in the figure 12. Note that DC motor “Model Parameterization” must be set

to “By stall torque and no-load speed”, since the mechanical portion is not connected yet.


Figure 12 – DC Motor Position and Velocity

Electrical Conclusions

In conclusion the theory behind the operation control of a DC motor was introduced and relates

to the context of the throwing a ball. The selection criteria for our desired motor were

discussed and a motor was chosen accordingly. DC Motor direction control was introduced and

applied to our electrical system in the form of PWM controlled H-Bridge circuit. A switch in the circuit was used to implement the reversal of direction feature on the DC motor allows the

throwing arm to both accelerate in the positive and negative direction to first accelerate the

ball, then release the ball and return the arm to its resting position. To maintain suitable

operating temperature, a heatsink was introduced and implemented into our system based on

values extracted from the datasheet. This increases the heat transfer coefficient of the system.

The passive heatsink was designed to be adequate and sized accordingly. Once satisfactory

results were obtained, individual parameters (rotor inertia, damping, PWM frequency, and Vm)

were adjusted to view the effects on the electrical system. Each parameter was discussed

thoroughly.

## Part B: Control

Control Introduction

The main objective of the control system is to create a position, velocity and current control of

the motor such that the ball follows trajectory. For this purpose, PI controllers are considered

by getting feedback from the actual values and comparing them to the desired values.

Control Design Criteria

The performance of the PI controllers is evaluated by checking the quantities such as error

overshoot and settling time. The settling time is referred to as the time it takes for the output

response to reach acceptable final values from the time the simulation starts. Respectively the

error is defined as the steady state value which would be the difference between the desired

value and the value attained in the experiment. The simulation file has been extracting both the

desired and the actual value under the same scope to clearly compare and observe the

difference between both values.

Each variable ”P” or “I” would modify certain characteristics of the scope when the value of P=1

is assigned it would entail that no effect on the scope is made and as the value of “P” decreases

it would entail and actual result with a greater error value therefore it would be considered that

a tune “P” value would lead to an outcome with a smaller steady stater error. As we increase

“P” the there would have greater overshoot before reaching steady state in the system. Further

tuning of the system can be achieved with the integral part of the controller

The tuning of the variable “I” the similarly increase the overshoot value of the experimental

result but helps decrease any offset from the desired steady state output, I is gradually

increased it is suitably close to the step input response. Because in this portion of the project

simulation of the “Derivative” is not the focus, an overshoot within the system is inevitable

In our experiment for this project both speed and current desired and actual values are

compared. Settling time is referred to the time it takes for the actual experimental value to

settle in the standardized range of +-5% [5] of the steady state value

The PI controller parameters are tuned manually for current and speed by observing the actual

values of current and speed and comparing them to the desired values. The PID values are

colored in yellow in the following shot for your reference

Figure 13 – Highlighted Portion of the PID controllers from the whole system

Design Stages of Feedback Motion Control System

Plant Transfer Function and Stability

In order to design a controller for our electro-mechanical system a transfer function must be

obtained using first principles.


Figure 14: Electromechanical Diagram of a DC Motor

Beginning with a KVL loop performed on the electrical side of the electro-mechanical diagram

we can obtain the following equation where Km is the motor constant, n represents the gear

ratio, ‘ω’ is the angular velocity of the motor shaft.

Where:

Now, on the mechanical side of the diagram we can examine the system from first principles,

using Newton’s 2nd law.

The summation of torque can be broken down into the torque produced by the DC motor

subtract the friction torque as shown below. Note that η is equal to the efficiency of the

gearbox, ‘n’ is equal to the gear ratio, ‘i’ is equal to the current passing through the DC motor, B is equal to the viscous friction, τs is the static friction and J is the rotational inertia of the

system.

Obtaining the Laplace transform of KVL equation and the equation above yield the following.

Knowing that the input into our system will be a voltage source and the output will be the

angular position of the motor shaft we can develop a state diagram.

Figure 15: State Diagram of a Geared DC Motor

Where;

Using the equation and state diagram above and if τs = 0 we can obtain the transfer function of

the plant.

Now that the transfer function has been obtained, it is worthwhile viewing the stability of the

plant through the root locus poles and zeros. Solving the characteristic equation, above yields

the following poles.

Table 2: Poles of Characteristic Equations

Pole 1 | 0
Pole 2 | -0.067
Pole 3 | -1.85x10³

Therefore, due to the location of the poles it can be shown that the system is stable under

certain conditions. It is noteworthy that Pole 3 is approximately –R/L which is also known as the

inverse of the electrical time constant. Pole 2 is within the order of B/J which is the inverse of

the mechanical time constant. Thus, the feedback system can be viewed within two-time

systems. The fast time system (electrical) and the slow time system (mechanical).

Using this understanding we can develop a cascade controller to implement current and

position feedback on our DC motor system.

Current Controller

Theory

Observing the transfer function of the current and voltage system we can find the transfer

function.

Figure 16: Transfer function for the Current and Voltage system

Which yields for the following transfer function:

Seeing as a pole and zero are in the same spot it is sufficient to say that they can be removed

from the system which yields the remaining transfer function.

Thus, the only pole is located at –1850. The system can be determined to be stable.

Integration

To tune our current controller a Simulink file was generated as shown below. A step input of 1

was applied and PI values were modified until a satisfactory system was created.


Figure 17: Current Controller Simulink File

In our first iteration PI values were selected arbitrarily as P=0.7 and the I = 1 and the results can

be found below. The settling time can be shown as 122.965ms. The percentage overshoot can

be observed to be approximately 15.

Figure 18: PID values of 0.7/1/0 respectively

To reduce the overshoot and improve the settling time, a much lower P value was selected and

a much higher I value was selected. The results can be shown below.

Figure 19: PID values of 0.0001/10.5/0 respectively

It is clear this system is drastically improved as the settling time has been reduced to 112ms and the overshoot percentage was reduced to 1.5%. These are the values we will proceed with in our cascade controller.

Speed Controller

Background

Figure 20: Transfer Function of the with the implemented cascade

After recognizing the relationship between current and torque and torque and speed it is

evident that the cascade motor controller can be implemented to yield a transfer function in

figure 20.

Implementation

The Simulink topology can be found below that was used to tune the speed controller.


Figure 21: Speed Controller Simulink File for Tuning


Figure 22: Actual Motor Velocity

Kp was selected to be approximately 120*L and Ki was selected to be 120*R as the default

values as determined in the control design. The error magnitude is incredibly large, and the

output is simply oscillating around the desired value of 1. Thus, a proportional constant was

implemented with the intention to reduce the absolute value and to converge much sooner on

the desired value of 1.

The system is much more stable than the initial design. Though the system stabilizes on a value

of 0.8 for our final design the proportional parameter will be increased until the output

stabilizes on 1. The overshoot % is still quite high and could be reduced by increasing the

integral parameter.


Figure 23: Actual Motor Velocity graph with P=0.8

Position Controller

Background

The position controller can be obtained using the above Speed controller and applying and

additional PI controller complete an additional cascade loop. No additional gain is required.

Tuning this system was the most sensitive as it with cascaded recursively with the speed and

current controllers. Performing simulations on this system was extremely tedious. Top layer of

the cascade control loop is the position control feedback loop. Position control is created by

adding a step input signal, and an additional PID block to the speed controller loop. Actual

position of motor is subtracted from step input signal, and the result is fed into the previous

system and considered as desired position.

Implementation

The system was modelled as shown below.

Figure X24 – Position Controller Simulink File

The first iteration of tuning the position controller was awful as it did not converge on our

desired value and oscillated on a value less than ours.

T

Figure 25: First Iteration of Position Controller

Performance Evaluation in Presence of nonlinearities

Nonlinearities can be caused by multiple factors such as friction, slip condition and electrical or

mechanical component values such as DC motor, H-bridge, gears etc. For this project, Long

March is working on simulation of a Throwing Robotic Arm, that was initially designed in

Solidworks, and simulations are done in Matlab Simulink. So, this section focuses on

nonlinearities in simulations.

Mechanical load variations can be caused by gear or revolt joint values. The following figure of

our Simulink design, and different mechanical components can be observed.


Figure 26 – Integration Mechanical Simulink Design with the Control and Electrical System

The following figure is scope results of position and velocity (desired vs. motor vs. joint) for the

original settings of mechanical loads. The following figure is like the previous one, except

changes in Simple Gear changing from 1 to 2 values have been implemented.


Figure 27 - Desired vs. motor vs. joint position and velocity with Simple Gear Ratio 1

Figure 28 – Changing Simple Gear follower to base ratio to 2


Figure 29 - Changing Simple Gear follower to base ratio to 3

As expected, “actual motor angle” and “actual motor velocity” have been expanded vertically

(by factor of 2) compared to the previous figure. Similarly, “actual motor angle” and “actual

motor velocity” will be expanded or compressed vertically depending on value of Simple Gear

follower to base ratio. Similarly, the following figure shows results when follower to base ratio

is changed to 3.


Figure 30 - Changing Simple Gear follower to base ratio to 0.5

The above figures show results of changing follower to base ratio to 0.5. The issue is that the

velocity stays non-negative, therefore, position of the joint never goes back to the original position when simulating the design. We were unable to find the exact reason in why this

occurs, but we believe that it could be either related to the edge cases of the calculations of

supplied torque, or the input threshold of the system to activate is not high enough to help

overcome the static friction in a high torque output system. These problems can be fixed by

revisiting equations in the PI controller, or adjusting the motor to help match the specifications

needed from the system

Table 3 – Rotational Friction Block parameters (original values)

Parameter Name | Parameter Value | Unit
| Rotational Friction
Breakaway Friction Torque | 0.00000000000001 | Nm
Breakaway Friction Velocity | 0.00000000000001 | rad/s
Coulomb Friction Torque | 0.00000000000001 | Nm
Viscous Friction Coefficient | 0.00000000000001 | Nm/(rad/s)

Another factor contributing to nonlinearities is frictions. In our design, we have Rotational

Friction block, that lowers power transition from motor to joint. The following figure shows

original settings or Rotational Friction block, which is realistically simulates zero friction.

Table 4 – Rotational Friction first iteration of test

Parameter Name | Parameter Value | Unit
| Rotational Friction
Breakaway Friction Torque | 2.5e-6 | Nm
Breakaway Friction Velocity | 5e-6 | rad/s
Coulomb Friction Torque | 2e-4 | Nm
Viscous Friction Coefficient | 5e-3 | Nm/(rad/s)

Two other runs were tested, and results can be seen in Figure X and Figure X.

Figure 31 – Too Much Friction, no Reverse Motion

Figure 32 – Limit Friction Where Arm Operates Normally

Table 5 – Rotational Friction Third iteration of test

Parameter Name | Parameter Value | Unit
| Rotational Friction
Breakaway Friction Torque | 1.25e-7 | Nm
Breakaway Friction Velocity | 5e-6 | rad/s
Coulomb Friction Torque | 1e-7 | Nm
Viscous Friction Coefficient | 5e-7 | Nm/(rad/s)

In addition to these causes that can contribute to nonlinearities in the system, parameter

uncertainties play an important role. For example, settings in the above figure (rotational

friction) will not be exactly like what has been demonstrated. The reason for that is physical

components have uncertainties that can affect overall performance of the system. To have

better simulations of the system, it could be beneficial to be able to measure different frictions

in the system and compare it to realistic values and revaluate motor selection in the future. It

could also be possible that the system is already performing at a “good enough” state where it

is able to perform all the necessary objectives given in the initial project description.

When studying the performance regarding Saturation Limits, our main concern is typically what

happens to our feedback control system when it begins reaching the physical limits of the

system [6]. This type of nonlinearity error occurs in the simulation when our control

engineering signal tries to apply an unrealistic signal in which case our H-bridge is not able to

keep up with the demands. To simulate the situation in which this would happen within our

Simulink simulation we will adjust different parameters within the system. Our goal is to create

a situation where we are making the PI controller wants a supplied output voltage greater than

what it is rated for. Without changing the motor specifications, we have decided to change the

Kp constant in the PI controller. What this will do is cause magnitude of the control signal

inputted into the system to change in relation to the constant. As we increase the Kp we should

see an increase in the desired voltage into the system, which at one point should go past the

values that the H-bridge can supply. From previous testing and block parameters, we know that

the system is limited to being able to supply a voltage of about ±11.6V, because torque and

voltage should have a positive relationship in our system, we should extrapolate when there is

saturation when desired torque increases but not actual torque. In figure [33] we can see when

comparing our Kp = 5 and Kp = 10, The actual torque values do not increase anymore despite the

desired torque still increasing.


Figure 33 – Desired Torque Graphs when Changing the Kp = 5, 10values

This could be demonstrating a case where the desired torque of the controller cannot be

matched by the physical limits of the system. Further testing would be required to find the

exact different limits of the system. From additional research, we have found that there are

three different methods that can be taken to help with dealing with saturation limits. These

methods are the following:

1. Consider the effects of the saturation in our design procedure of the controller
2. Modeling Predictive Control (MPC), which is known as a form of moving horizon control
3. By using a two-step system, where a nominal linear control system is construct ignoring

saturation (ex. Standard Linear design tool), and then applying an “anti-windup

compensator” which is designed to handle saturation constraints. [7]

As of right now, we believe that these methods exist outside the scope of this course and

project, so they have not yet been implemented. If required for performing the actions of the

system, they will be investigated for further detail and implemented.

Control Conclusions

The PI controller's parameters are chosen for the best performance of the system. Seeing as the

design criteria was to implement an accurate, repeatable, and reliable system each respective

controller must be as precise as possible. Particularly when using a cascade controller where

each value is used in the next controller it is imperative that each layer has been tuned

correctly. According to the simulation results, the following parameters are selected for current

and speed controllers respectively: Current: Kp= 0.0001, Ki=10.5 which lead to a 122ms settling

time and a 1.5% overshoot., Speed: Kp=, ki=0.1 (for which the actual speed follows the desired

speed almost perfectly during the ramp).

## Part C: Integrating Part A and Part B

Long March selected Design II from the Mechanical Project to be integrated with electrical and

control systems project. Initially, a sperate Simulink file was created to solely simulate the

mechanical design. For this project, that Simulink code was integrated with mechanical section

of the current design, as it can be seen in the following figure.


Figure 34 – Mechanical section of current Simulink model

Long March completed two separate labs that prepared us for this project. The first lab, which

was focused primarily on electronics components of this design (e.g. DC motor and H-bridge).

Purpose of lab 1 was to design and implement a bi-directional DC motor that is controlled by

Controlled PWM Voltage Source in Simulink. Overall, the main goal was to become familiar with

Simscape electrical by constructing the DC motor (GM8724S009) and H-bridge (TB6568KQ) to drive the motor. Additionally, our team used the model created in lab 1 for the project. Purpose

of lab 2 was to design and test feedback controllers in Simulink by using the circuit created in

lab 1. In addition, three separate loops were created to control the current (actual current),

speed and trajectory (position) of the Throwing Robotic Arm. Similar to lab 1, lab 2 was also

used for the main project. Finally, Long March integrated the Simulink file created for Design II

Of the mechanical project into the file that was created for lab 2. Our group faced multiple

warnings and errors, so we had to test different sections of our Simulink program (electrical,

control or mechanical) to troubleshoot. For example, when the current control loop was not

working properly, a step input was used (instead of the desired current input) to test that

specific loop. In addition, multiple scopes were connected to each section of the program in

order to understand how values are changing and debug the problem. Similar to testing for the

current loop, a step signal was also used for speed or position feedback loops, and also the

input to mechanical portion.

Table 6: Rotational Friction Simulation Parameters

Parameter Name | Parameter Value | Unit
| Rotational Friction
Breakaway Friction Torque | 1.25e-7 | Nm
Breakaway Friction Velocity | 5e-10 | rad/s
Coulomb Friction Torque | 1e-7 | Nm
Viscous Friction Coefficient | 5e-7 | Nm/(rad/s)

Once the program was running without any errors, the simulation of the Robotic Arm was

unsuccessful. So, we had to move back from mechanical portion of the system to control and

electrical parts. We realized the problem was with the Rotational Friction block, since the

default values in Simulink are implemented for much larger systems, and the power applied for

this project is much smaller than those values, hence effects of friction are much more

noticeable. Therefore, we tested our model with values seen in the following figure, which is basically zero friction. For more details, refer to “Performance Evaluation and Presence of

Nonlinearities” section.

Final integration and Next Steps

### References

[1] Pittman Express GM8724S009 Datasheet
[2] “The Complete Guide to DC Motors,” RS. [Online]. Available: https://ie.rs-

online.com/web/generalDisplay.html?id=ideas-and-advice%2Fdc-motors-guide. (https://ie.rs-online.com/web/generalDisplay.html?id=ideas-and-advice%2Fdc-motors-guide)

[3] “Mathworks,” DC Motor Model - MATLAB & Simulink. [Online]. Available:

https://www.mathworks.com/help/physmod/sps/ug/example-modeling-a-dc-

motor.html. (https://www.mathworks.com/help/physmod/sps/ug/example-modeling-a-dc-motor.html) [Accessed: 25-Jul-2021].

[4] Toshiba TB6568KQ Full-Bridge DC Motor Driver IC Manual
[5] “Settling Time,” RS. [Online]. Available: https://en.wikipedia.org/wiki/Settling_time
[6] Haidekker, M. A. (n.d.). “Saturation Effect.” Saturation Effect - an overview ScienceDirect

Topics. https://www.sciencedirect.com/topics/engineering/saturation-effect. [Accessed:

25-Jul-2021]

[7] Souad Bezzaoucha, Benoît Marx, Didier Maquin, José Ragot. Linear feedback control

input under actuator saturation: a Takagi-Sugeno approach. 2nd International

Conference on Systems and Control, ICSC 2012, Jun 2012, Marrakech, Morocco.

pp.CDROM. ffhal-00687739f

### Appendix


Figure 35 – Overall View of Long March Design

Part A: Electronics Project

Table 7: Simulink Parameters from TB6568KQ Full-Bridge DC Motor Driver Datasheet

Parameter Name | Parameter Value | Unit
| Input Threshold
Enable Threshold Voltage | 2.5 | V
PWM Signal Amplitude | 18 | V
Reverse Threshold Voltage | 2.5 | V
Braking Threshold Voltage | 2.5 | V

Bridge Parameters

Output Voltage Amplitude | 12 | V
Total Bridge on Resistance | 0.1 | Ohm
Freewheeling Diode On Resistance | 0.05 | Ohm
Freewheeling Diode Off-state Conductance | 1e-6 | S
Measurement Temperature | 25 | °C

Table 8: GM8724S009 DC Gearmotor Simulation Parameters

Parameter Name | Parameter Value | Unit
| Electrical Torque
Field Type | Permanent Magnet | N/A
Model Parameterization | By Rated load and Speed | N/A
Armature Inductance | 2.34 | mH
No Load Speed | 720 | rpm
Rated Speed (At rated load) | 400 | rpm
Rated Load (Mechanical Power) | 10 | W
Rated DC Supply Voltage | 12 | V
Rotor Damping Parameterization | By Damping Value | N/A

Mechanical

Rotor Inertia | 1.6e-6 | Kg*m^2
Rotor Damping | 1.1e-4 | Nm/(rad/s))
Initial Rotor Speed | 0 | rpm

Table 9: Controlled PWM Voltage

Parameter Name | Parameter Value | Unit
| Pulse Width Modulation
PWM Frequency | 4000 | Hz
Simulation Mode | Averaged | N/A
Output Voltage Amplitude | 40 | V

Part B: Control Project

Control Function Code

Figure 36 – Control Function Code


Figure 37 – MATLAB Simulink blocks for Electrical

Figure 38 – MATLAB Simulink blocks for control


Figure 39 – MATLAB Simulink blocks for Mechanical Integration

Figure 40 – MATLAB Simulink Blocks Integrated Controls, Electrical, and Mechanical

### Project – Electrical/Control Report Contribution

Note: During the first two meetings we discussed task allocation and were not certain as a team

of how to move forward. Therefore, no serious tasks were completed prior to Meeting 3.

Meeting 3 - 18, July, 2021

Attendees: Everyone

During this stage of the project, we did the following tasks:

1. Design and complete hand calculations for the H-bridge
2. Complete DC motor and H-bridge calculations based on data sheets
3. Complete current controller for lab 2

Contribution of each member from the previous items:

- Sepehr: Task 2 and task 3
- Chad: Task 1 and task 2
- Arash: -
- Darwin: - Task 2 Task 3

Meeting Notes

- Ask TA whether we need to design the h-bride or hand calculations are sufficient.
- Asked Darwin to integrate Simulink design from Mechanical section of the course to our current design.

Meeting 4 - 19, July, 2021

Attendees: Everyone

During this stage of the project, we did the following tasks:

1. Test the current controller and make sure the graph looks realistic
2. Update design 2 Solidworks so it matched Matlab simulation
3. Update the Mechanical project simulation
4. Continue working on heat sink hand calculations
5. Prepare presentation for TA meeting.

Contribution of each member from the previous items:

- Sepehr: Task 1 and task 5
- Chad: Task 4
- Arash: Task 2
- Darwin: Task 2, Task 3

Meeting Notes

- How to resolve the issue of importing files from Solidworks to Matlab (we get an error)

Meeting 5 - 20, July, 2021

Attendees: Everyone

During this stage of the project, we did the following tasks:

1. Integrate the Simulink blocks from mechanical project’s simulation to our current file for elec/control project, and test whether simulation is created in the new file
2. Complete the function in the function block that updates desired value for position/vel/acc continuously
3. Complete the speed control and position control
4. Design a gpio block (based on instructor’s notes) to faciliate direction control
5. Update cup of the mechanical design

Contribution of each member from the previous items:

- Sepehr: Task 1, task 2 and task 3
- Chad: Task 4
- Arash: Task 5
- Darwin: Task 1, Task 5

Meeting Notes

- Create a “What’s left” file on team’s Google drive so that tasks are more organized and clear
- Make sure everyone is using the most recent version of MATLAB

Meeting 6 - 20, July, 2021

Attendees: Sepehr - Arash

During this stage of the project, we did the following tasks:

Troubleshoot Matlab errors

Contribution of each member from the previous items:

- Sepehr:
- Chad:
- Arash:
- Darwin:

Meeting Notes

Meeting 7 - 22, July, 2021

Attendees: Chad – Arash – Sepehr

During this stage of the project, we did the following tasks:

1. Test the system with different parameters/ variables and observe results
2. Figure out the problem occurred while integrating Solidworks files into Simulink
3. Calculate pid block’s values and use most suitable values for our design

Contribution of each member from the previous items:

- Sepehr: Task 1 and task 2
- Chad: Task 1
- Arash: Task 1 and task 3
- Darwin:

Meeting Notes

- Create a “What’s left” file on team’s Google drive so that tasks are more organized and clear
- Make sure everyone is using the most recent version of MATLAB

Meeting 8 - 24, July, 2021

Attendees: All members were present

During this stage of the project, we did the following tasks:

- Assigned responsibilities for the report:
1. Introduction
2. Electronics Introduction
3. Motor Selection
4. Design Stages of Power Electronics Drive Circuitry
5. DC Motor Control
6. Thermal Design for PWM Chip
7. Simulation Results for Evaluation Power Drive Circuit Operation
8. Electronics Conclusion

9. Control Introduction
10. Control Design Criteria
11. Design Stages to Support Control Design Process
12. Performance Evaluation in Presence of Nonlinearities
13. Control Conclusions
14. Integration
15. General Formatting

Contribution of each member from the previous items:

- Sepehr: Tasks 7, 12, 14, 15
- Chad: Task 1, 2, 3, 4, 5, 6, 7, 8, 10, 11, 13 15
- Arash: task 1 ,9
- Darwin: 1,7, 12,13,14,15
Meeting Notes
- Meet at 7pm on due date to do final grammar checks prior to submission.

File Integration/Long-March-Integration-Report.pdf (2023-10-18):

MSE 312: Mechatronics Design II
Summer 2021

# Integration for a Throwing Robotic Arm:

Student Name | Student ID
Darwin Chang | 301315054
Chad Graham | 301308419
Sepehr Rezvani | 301291960

Prepared by: Long March
Submission Date: August 9th , 2021

ii

## Abstract

Long March completed mechanical, electrical and control system of a throwing robotic arm that lunches a Lacrosse ball. This report shows the process of completing integration portion of the project. In addition, the report includes total cost breakdown, innovation, analysis, and improvements our team made in the process. Our team learned that every subsection of project must be perfected, otherwise small errors add up causing inaccuracies. For instance, this report includes results of our demonstration, errors and what caused those errors. It was concluded that multiple factors contributed to demonstration results being inaccurate. By understanding our mistakes, readers can use suggestions made in this report to improve and optimize their simulation results.

iii

## Contents

1

## Introduction

This mechatronics design project was proposed to test and develop our mechanical, electrical,

and controls skills. It also provided an opportunity to simulate an industrial project with

randomly assigned groupmates while working remotely. It taught us valuable lessons on

working in a group, delegating tasks, and organizing focused and productive meetings. Long

March was ultimately tasked with designing a throwing mechanism that is capable of accurately

and repeatedly launching a projectile with known mass and size, in this case, an NCAA rated

lacrosse ball, to a randomly assigned distance within 0.2-1.5m. This report seeks to

demonstrate the integration process of the project. Combining a mechanical, electrical, and

control system into a functioning simulation that solved the assigned problem. The report will

review the total cost breakdown, innovation, analysis, and improvements made throughout the

project. These results will be discussed in-depth and suggestions for improvements will be

introduced.

2

## Total Costs

Provided a $500 budget this project provided ample room to complete the design. The project

ultimately came in under budget with a price of $291.01. Our frame’s primary material was

standard 6061 30x30mm aluminum extrusion. An advantage of using extrusion is the vast

number of available fasteners. This prevents us from needing to weld, drill, tap, or any other

time-consuming and expensive connection process. The bucket was also constructed using thin

aluminum sheets that are can be easily modified to the desired dimensions. Since we used

simple materials, they can be constructed at one of the group member’s houses for zero cost.

It should be noted however that our design only actually required 83cm of extrusion for the

entire frame. However, the minimum size that can be purchased is the full 5.3m. This means

there are approximately 4.5m that could be used for other projects, sold to minimize cost

towards project, or the 83 cm amount could be retrieved from a local company using their

scraps.

Table 1: Project Cost Breakdown

Item Description | Part Number | Manufacturer | Lead Time (Weeks) | Cost (CAD)
Servo Motor [1] | 82890001 | Crouzet | 2-3 | $136
Motor Controller [2] | EV-VNH7040AY | STMicroelectronics | 1-2 | $8
30x30mm Aluminum 5.3m Extrusion [3] | 670085 | TSLOTS | 0-1 | 93.03
M6 T-Slotted Nuts x 12 [4] | 664112 | TSLOTS | 0-1 | 24


3

M6 x 12mm Black Oxide Finish Steel Socket Cap Screw [5] | 11103339 | Fastenal | 0-1 | 20
1566 Carbon Steel Shaft | 1346K11 | McMaster Carr | 1-2 | 10
Total Cost | | | | 291.03

## Innovative and Creative Design

Figure 1: Mangonel Styled Catapult [7]

Simple and reliable. Our approach to our design is a modern interpretation of an ancient relic,

the Mangonel catapult. The Mangonel consists of a long wood arm with a bucket (early models

used a sling) with a rope attached to the end. The arm is then pulled back (from a natural 90o

angle) then energy was stored in the tension of the rope and the arm. Then the bucket would

be loaded. When released the Mangonel's arm would return to its equilibrium position, when it

encountered the beam (or block) the arm would stop but the missiles stored in the bucket

would continue to launch toward the enemy. The Mangonel fired projectiles in an overhead

arc, the angle of the path of the projectile could be determined by a block placed on the beam

that stopped the Mangonel's arm by using a block that stopped the arm earlier than 90o angle

would result in a path angle (above the horizontal) equal to the angle between the arm and the 90o angle. [6]

Our design differs by using state-of-the-art DC motors and cascade controllers to precisely land

the ball at the desired position. Each level of control was tuned to near perfection beginning

with the current, then speed, and finally, position. It is constructed using aluminum extrusion

that permits minuscule adjustments and mechanical tuning to be performed using a simple hex


4

key and without drilling and tapping new holes. Instead of tension in the arm, torque will be

generated using a gearbox between the motor shaft and the shaft of the system.

## Improvements

Motor Upgrade

During the testing phase of our control system, we encountered a recurring issue where the

motor would reach saturation before moving the arm with the ball. This made tuning near

impossible as the actual current, speed, and position would oscillate wildly around the desired

value or even shoot off to infinity. This can be seen in Figure 2 below.

Figure 2: Position Vs. Time of Old Motor

Even with friction reduced to 10^-12 the shaft would not move as intended. Ultimately, we

decided to compromise the low-power version for a stronger motor and motor controller. This

increase of rated current increased the torque to be within the nominal range required to move


5

the arm. We decided the increase in power and cost was worth the trade-off. See below for an

overall specification comparison between the two motors.

Table 2: Motor Comparison

Specification | Initial Motor GM8724S009 From Lab | Final Motor 82890001[1]
Rated Torque | 0.1Nm | 0.270Nm
No Load Speed | 720rpm | 3200rpm
No Load Current | 1.2A | 3A
Rated Voltage | 12V | 24V
Power Consumption | 4W | 10.8W

After changing the motor for a more powerful one, even before tuning, it was rapidly apparent

that our issue was mitigated. Even with friction on the order of magnitude 10^-2 the arm would

rotate to the desired value. Brief tuning yielded the result below.

Figure 3: Desired and Actual Position vs Time - Final Motor

The decision to upgrade the motor yielded positive results. The motor was capable of launching

the heavy projectile to the required distances and in a predictable manner.


6

Fixing Simulation Breaking Bugs and Optimizations

For simulations improvements, they can be split into two main groups. The first group is

adapting the system so that it works and runs properly, and the second group is tweaking the

system so that it is optimized.

Updated Cup Model

There are a few problems that needed to be fixed before the simulation would not act

unreasonably. The initial problem that we ran into was our cup design was not the best for both

holding the ball and importing it into MATLAB’s Simulink. The initial design we used was a cone-

shaped cup for the ball shown in the figure below:

Figure 4: Left: Initial Cup Design, right: Updated Simulation Cup model

The two issues we realized with this design early on were during higher rotational speeds of the

arm, it is not realistic to assume that the ball would remain stationary relative to the cup, and

secondly, based on how Simulink imports SolidWorks models, it models concaved objects as a

filled solid, which causes any object within it to act like it is on a trampoline. This would cause

the ball to launch due to this spring force and not kinetic energy transferred from the arm. This

was fixed by adjusting the model to be a box with an open top and four rectangular solids

7

Rotational Actuation Joint Limits

Using joint limits, we were able to create better simulations outputs and get values closer to

the desired results. For the majority of the results, we limited the rotational joint to -45 to -140

degrees for the upper and lower bound. If this is not done, it would cause the ball to not launch

out of the container.

Table 3: Comparison of Simulation with and without Rotational joint limits

Results 0.83m

| With Joint Limit | Without Joint Limit
X Landing Position of Ball (m) | 0.82894 Meters | 0.035808 Meters
Error X Landing Position of Ball (m) | 0.0010636 Meters | 0.79419 Meters
Y Max Position of Ball (m) | 0.37312 Meters | 0.071648 Meters
Time taken for Simulation | 0.56712 Seconds | 0.43823 Seconds
Total Power Usage (W) | 258.4577 Watts | 204.6149 Watts
Elapsed time (s) | 11.370518 seconds | 11.674869 seconds

Something that should be noted is that depending on the actual real-life use case of the system,

a hard stop to the joint limit might not be feasible. Typically, abrupt stops to a system, whether

mechanical or electrical could cause harm to the integrity of the system. For now, a mechanical

stop to the system will prove to be cheaper, but at the cost of a shorter life span of the system

Optimizations of Simulation

Table 4: Spatial contact Force vs Contact Force Library

Results 0.83m, Comparison with Spatial Contact Force vs Contact Force Library

| Spatial Contact Force | Contact Force Library
X Landing Position of Ball (m) | 0.82894 Meters | 1.0053 Meters
Error X Landing Position of Ball (m) | 0.0010636 Meters | -0.17527 Meters

8

Y Max Position of Ball (m) | 0.37312 Meters | 0.35918 Meters
Time taken for Simulation | 0.56712 Seconds | 0.56154 Seconds
Total Power Usage (W) | 258.4577 Watts | 268.8284 Watts
Elapsed time (s) | 11.370518 seconds. | 15.073665 seconds.

In the table above we have demonstrated the time difference of the simulation. What should

be noted here is not so much the accuracy of the system between each of the block libraries

used as the parameter tuning of each block is slightly different which is the main cause of the

difference in position, but instead the elapsed time difference. The difference in time is almost

equivalent to 50% slower using the contact Force library compared to the Spatial Contact force.

This change in the system allows for faster compilation of the system with the integration of

the system, as one block is just more optimized than the other.

Another way we have optimized the simulation was how we have measured the position of the

ball at certain points in time. In the initial design of the Simulink block what we had in mind to

obtain the value such as when the ball lands are obtaining the value of X-position when y is

equal to the radius of the ball. We found with this logic of obtaining the value was that

sometimes it would not work. We determined that due to how Simulink MATLAB works in

discrete values, y distance will not necessarily be equal to a certain value we want. To fix this

the system was changed to a latch system that works in conjunction with a hit crossing probe to

detect if the ball passes a value ever so slightly above the radius of the ball.

Solving Input Parameters Based on Desired Landing Position

Long March had multiple ideas to design a system that solves for input parameters, W_cruise,

T_ret, q_ret and a_ret. These variables are rotational speed arm from T_ramp (ramp time) to

T_ret (time of retraction), time of retraction, the position of the arm and angular acceleration

of arm at the time of retraction, respectively.

Initially, we wrote a Matlab function that had four inputs and four outputs. Inputs were

Pos_fin_x, Pos_fin_y, T_fin and r. These are desired landing position in x and y direction, final

time of simulation, and radius of arm (rotational radius), respectively. Outputs were W_cruise,

9

T_ret, q_ret and a_ret. Then we wrote a function called ‘practice.m’ that solves for outputs

using Matlab’s ‘Solve’ function. Once the code was tested with the Simulink file, it was giving

imaginary values for outputs. Therefore, we had to assume a_ret as a known parameter for

Trial 2 instead of solving for it during the next stage of out design. This code will be included in

‘Trial 1’ folder, and will include ‘main.m’ (main function that calls solver function), and

‘practice.m’. Table 5 shows function call, number of inputs and outputs in the main script and

practice function.

Table 5: Inputs and Outputs in ‘main.m’ and ‘practice.m’

Outputs | Inputs

‘main’ script

[W_cruise, T_ret, q_ret, a_ret] | (2.5,0,T_fin,r)

‘practice’ function

[W_cruise2, T_ret2, q_ret2, a_ret2] | (Pos_fin_x1, Pos_fin_y1, T_fin1, r1)

Next, we followed a similar process, but chose a_ret to be constant. The problem in this trial

was that T_ret solved, but results were unreasonable. In some cases, negative, in others bigger

that 1, which was incorrect since T_fin was 0.5. Table 6 shows how the program solved for

T_ret, while changing a_ret. It can be observed that there is a mistake, either in the code or in

the Simulink design. This code will be included in ‘Trial 2’ folder.

Table X – T_ret Relationship with a_ret (T_fin = 0.5)

Table 6: shows function call, number of inputs and outputs in the main script and practice function.

Return Acceleration: a_ret | Return Time: T_ret
-1 | -1.2321
-3 | -0.5000
-5 | 1.2746
-7 | 1.1547

10

Table 7: Inputs and Outputs in ‘main.m’ and ‘practice.m’

Outputs | Inputs

‘main’ script

[W_cruise, T_ret, q_ret] | (2.5,0,T_fin,r)
| ‘practice’ function
[W_cruise2, T_ret2, q_ret2] | (Pos_fin_x1, Pos_fin_y1, T_fin1, r1)

Then it was observed that using a constant for q_ret as well seems to be the only solution, and

always solves for T_ret within reasonable range. This code will be included in ‘Trial 3’ of folder.

Note that Matlab files in trial folders are intended observation of coding progress. Simulink file

is not included, hence Mechanics Explorer does not run. Details of this code will be explained in

‘Analysis and Evaluation’ section of this report. Table 8 shows function call, number of inputs

and outputs in the main script and practice function.

Table 8: Inputs and Outputs in ‘main.m’ and ‘practice.m’

Outputs | Inputs

‘main’ script

[W_cruise, T_ret, Vel_fin_y, limit_value] | (des_pos,0.0315,T_fin,0.14,q_ret,a_ret)

‘practice’ function

[W_cruise2, T_ret2, Vel_fin_y2, limit_value] | (Pos_fin_x1, Pos_fin_y1, T_fin1, r1,
| q_ret1,a_ret)

Note: q_ret and a_ret constants have been added to inputs. Vel_fin_y (ball velocity in y-

direction, at landing) and limit_value (arm’s starting angle) have been added to outputs.

Another code change that improved our virtual prototype was introducing multiple if/else loops

in ‘practice.m’ function. Long March proposed multiple solutions that can increase accuracy of

landing position. Eventually, it was observed that q_ret must be manually changed based on

desired landing position given by the instructor. In a perfect virtual design, q_ret must be

solved automatically. However, as mentioned in the previous paragraph, q_ret was chosen to

11

be a constant. Therefore, q_ret was selected by trial and error for each landing range based on

‘Pos_fin_x’. Refer to ‘Trial 3’ folder to see code changes.

Last change that contributed to design improvement was introducing limit_value in ‘practice.m’

function. When Long March was testing desired landing positions that were relatively further

(>1.2m), it was observed the ball does not seem to reach that far. Since the electrical system

was already tuned and could not choose a stronger DC motor, we changed initial arm position.

In ‘practice.m’, it can be seemed values of limit_value is decreasing for further throws,

indicating lower initial arm position. Refer to ‘Trial 3’ folder to see code changes.

12

## Results

Given Desired Throwing Positions 0.22, 0.83, 1.27

For 0.22 a value of 0.245 was inputted during demonstrations as 0.22 was not working as

intended due to unknown reasons. As the presentations were not recorded to reobtain the

output values, the simulation was a rerun, which may cause simulation and elapsed time to

vary slightly than on presentation date.

Table 9: Results of 0.22m Desired Position w/ Simulation

Results 0.22m (Input 0.245)

X Landing Position of Ball (m) | 0.21373 Meters
Error X Landing Position of Ball (m) | 0.031267 Meters
Y Max Position of Ball (m) | 0.26466 Meters
Time taken for Simulation | 0.52295 Seconds
Total Power Usage (W) | 212.1716 Watts
Elapsed time (s) | 10.980934 seconds.

Table 10: Results of 0.83m Desired Position w/ Simulation

Results 0.83m

X Landing Position of Ball (m) | 0.82894 Meters
Error X Landing Position of Ball (m) | 0.0010636 Meters
Y Max Position of Ball (m) | 0.37312 Meters
Time taken for Simulation | 0.56712 Seconds
Total Power Usage (W) | 258.4577 Watts
Elapsed time (s) | 11.370518 seconds.

13

Table 11: Results of 1.27m Desired Position w/ Simulation

Results 1.27m

X Landing Position of Ball (m) | 1.2388 Meters
Error X Landing Position of Ball (m) | 0.031177 Meters
Y Max Position of Ball (m) | 0.4365 Meters
Time taken for Simulation | 0.60964 Seconds
Total Power Usage (W) | 320.7294 Watts
Elapsed time (s) | 10.782429 seconds.

Table 12: Results of Max Y Position w/ Simulation

Results Highest Throw (input of 1.5m, lower Limit=-140, upper Limit = -90)

X Landing Position of Ball (m) | -0.013352 Meters
Y Max Position of Ball (m) | 0.52308 Meters
Time taken for Simulation | 0.66496 Seconds
Total Power Usage (W) | 462.8029 Watts
Elapsed time (s) | 11.488490 seconds

Table 13: Results of Furthest Position w/ Simulation

Results Furthest Throw (input of 1.5m, lower Limit=-140, upper Limit = -45)

X Landing Position of Ball (m) | 1.4983 Meters
Y Max Position of Ball (m) | 0.47328 Meters
Time taken for Simulation | 4.1461 Seconds
Total Power Usage (W) | 454.5162 Watts
Elapsed time (s) | 22.094963 seconds.

14

## Analysis and Evaluation

Landing Position Testing

Once the Simulink program was improved, Long March’s goal was to throw the ball with high

accuracy by improving the Matlab code. To achieve that goal, our team focused on two things:

first selecting kinematics formulas, then modifying the ‘practice.m’ code. In this section, we will

explain how these two factors contributed to demonstration results, and how they can be

improved in the future.

As mentioned in the Improvements section, the ‘main’ script solves for W_cruise and T_ret,

uses those values and other parameters to run the Simulink program after. During our

demonstration, three desired landing positions were given, and our simulation had 2.85%,

0.12%, and 2.46% error for each throw. One factor contributing to these errors is the kinematic

formulas used. Here are two main formulas used for solving unknowns, W_cruise and T_ret:

For a more detailed explanation of how ‘practice’ function was created, refer to Appendix.

These equations were used for a perfect throw condition without considering forces acting

against the arm or ball at retraction time. So, these factors could have affected final errors. For

future work, friction (for e.g. air friction) can be implemented in formulas to increase accuracy

of final results.

Second factor that had a major effect on final errors is ‘practice’ function. As mentioned, in last

part of ‘Improvements’ section, we had to choose q_ret by trial and error depending on desired

landing position. Figure X is a sample of ‘practice’ function.

Figure 5: Sample Selected from 'practice' function

15

It can be observed that q_ret is manually set depending on Pos_fin_x (desired landing position

in x-direction). So, we can be certain that error will be minimal if Pos_fin_x is divisible by 0.05

m, since that is how ‘practice’ function was created. During our demonstration, neither of three

values given were divisible by 0.05 m, hence contributing to error. For future work, we can

increase number of if/else loops in the ‘practice’ function to include more possible landing

position ranges.

Accuracy of Position

Overall, the results did not exactly meet the project requirements we set out to complete of

being able to hit our target of ± 2cm of the target system. When we did our final testing, we

were mainly concerned with values from 0.2 meters to 1.5 meters at intervals of 0.05 meters.

Most of our simulation values were able to obtain these values relatively closely. We were able

to get close to the desired position in two of the positions (0.22 and 1.27 meters) and get within

2 mm of the last position (0.83). With our testing method, we had assumed that the

intermediate values between each input and output of the tested values would have a linear

relationship. This was not the case. During our live presentation, the input value of 0.22 did not

output a very desirable outcome. After receiving the approval of Dr. Helen Bailey, we

reattempted the simulation run with an input value close to the desired but not the desired. In

our case, we used the value of 0.245m. This input gave us an output of 0.21373 meters. This

gives us a percent error of 2.85% and a value of 6mm off from the desired (Observed from the

table below).

Table 14: Error Table for Each of the Demonstration Values

Desired Position (m) | Actual Position (m) | Error (m) | % Error
0.22 | 0.21373 | 0.00627 | 2.85%
0.83 | 0.82894 | 0.00106 | 0.13%
1.27 | 1.2388 | 0.0312 | 2.46%

This relationship can be observed somewhat in other values in the simulation. It is also possible

that input values used can give pretty accurate output results. The biggest issue right now is the

reliability of our results. A good portion of our values is” hardcoded” and does not change at a

16

high enough resolution for example qret. This error is compounded by the fact that it is

required for us to create joint limits for the system to work properly. The most pertinent issue

with our simulation right now is to reevaluate the logic of our code and double-check if the

system is performing as we intended. This would require extensive bug checking and creating

reasonable test cases for the system. As it stands, our simulation could be made more accurate

and better through less hard coding of values like qret or hard limits on the joints instead of

being set through the controls system, and the introduction to more equations and

relationships between the parameters.

Simulation Time Improvements

Our ability to eliminate irrelevant portions of the robotic arm to the simulation has allowed us

to help lower the simulation time to a total of only 33.13 seconds for all three simulation

distances. Some of the techniques optimizations routes we have taken include modeling of the

motor on the robotic arm system. It is undoubtedly computationally heavy to have to create

and animate the motor attached to the arm shaft. It would have looked better in simulation but

it would not change our outputs as the parameters of the motor are already considered in the

Simulink program. Although our simulation is already somewhat fast it can be improved by

looking at if certain values can be calculated faster in our function, or if the logic between

blocks of the Simulink can be wired more efficiently. We believe that improving how values are

computed and how the program run will provide the most meaningful change to the system is

because Matlab’s Simulink acts as a while loop that works with really small discrete values over

time. If an operation or logic can be evaluated with one less time each loop, then throughout

the run, it could save potentially thousands of instructions. From the simulation output, we can

see in a simulation time of 1.2407 seconds long, the simulation has created over 2000 output

values for one variable.


17

Figure 6: Simulation Outputs

We can also look to see if it is possible to calculate each of the output values off of one variable

as opposed to each variable individually. So certain high-cost calculations concerned with only

the final values will only have to be done once as opposed to for each variable.

Simulation Realism

From our current system, we have elected to omit a pretty important factor that exists in real

life, friction. This parameter would reduce the accuracy of our system in a real-life situation.

The reason we have chosen to neglect this portion of the system is because of the high

computational power needed in simulating aspects like aerodynamics of a system or air

resistance, or complications it would add to our equations with values like friction between the

ball and the cup or the shaft and the supporting beams. The next steps to improving the realism

of the system would be through simulating better frictional values between the cup and the ball

in the system and taking them into account in our functions when solving for parameters to

input to the system.

Additional assumptions were subtle deflections in the mechanical system itself and the

withdraw of bearings along the shaft. These assumptions were made due to the marginal,

though non-zero, error it would cause in the simulation. If the design were to be created in real

life these critical parameters would have to be accounted for.

18

## Conclusions and Further Work

In terms of the initial deliverables set out for this project, we were able to satisfy most of the

constraints. Here are the main constraints of the project in comparison to our simulation in

numbers:

1. Total Cost of Under $500, ours being 291.03
2. Total Simulation Time of under 3 minutes, ours being 33.1332 seconds of elapsed time
3. Operating Radius of under 30 cm, ours being 25 cm in operating radius
4. Throwing distance of 0.2-1.5 meters, ours being 0-1.5 meters
5. Resolution of throwing accuracy ±2 cm, ours being ±5 cm

Of the main constraints satisfied, we were able to satisfy constraints 1-4, with only the

resolution of throwing accuracy being slightly off. Unfortunately, we were not able to properly

create a model and simulate a Robotic Arm to an accuracy of ±2cm. Although the accuracy of

the system could not be achieved, we were still able to get it in the range of ±5cm. For further

improvements into the system, the main project goal would be to be able to control the robotic

arm to throw the lacrosse ball to an accuracy of ±2 cm. To do this we would have to revisit the

parameters of the system, how they were created, and how the Simulink diagram handles the

input parameters.

Aside from being able to model how the “perfect” model performs in the real world, this

project does not take into manufacturing tolerances of the system. At the end of the day, our

SOLIDWORK file imported into the simulation has been created with basically perfect fittings.

With different manufacturing tolerances. For further works in the future, we should investigate

how the manufacturing of the system would work, and to what degree of tolerances the system

needs to adhere.

19

## References

[1] P. C. B. E. K. Y. S. Chain, “82890001 Gear Servo,” PCBEKY Supply Chain, 26-Jul-2021. [Online]. Available: https://www.pcbekey.com/products/1_585431/82890001. [Accessed: 09-Aug-2021].
[2] “Ev-vnh7040ay,” DigiKey. [Online]. Available: https://www.digikey.com/en/products/detail/stmicroelectronics/EV-VNH7040AY/7691037. [Accessed: 09-Aug-2021].
[3] “670085,” Proax. [Online]. Available:
https://www.proax.ca/en/product/1338767/TSL670085. [Accessed: 09-Aug-2021].
[4] “664112,” Proax. [Online]. Available:
https://www.proax.ca/en/product/1337048/TSL664112. [Accessed: 09-Aug-2021].
[5] “Carr,” McMaster. [Online]. Available: https://www.mcmaster.com/1346K11/. [Accessed: 09-Aug-2021].
[6] “History of catapults - physics of catapults,” Google Sites. [Online]. Available: https://sites.google.com/site/physicsofcatapults/home/history-of-catapults. [Accessed: 09-Aug-2021].
[7] “Catapult,” Wikipedia, 24-Jun-2021. [Online]. Available: https://en.wikipedia.org/wiki/Catapult. [Accessed: 10-Aug-2021].


20

## Appendices

Appendix A: Analysis and Evaluation

Landing Position Testing
This section included hand calculations and shows how the ‘practice’ function was created.

Table 15 gives a brief description of each variable. Note that ‘initial’ and ‘final’ position of the

ball are based on Figure 7.

Figure 7: Free Body Diagram of the Ball at Retraction Time

Table 15: Variable Names, Description and Status

Variable Name | Description | Status
Pfx | Ball position when lands (x-axis) | Known
Pix | Initial ball position (x-axis) | Known
Pfy | Ball position when lands (y-axis) | Known
Piy | Initial ball position (y-axis) | Known
r | Radius of the arm | known
ωcruise | Angular velocity of ball between ramp time and retraction time | Unknown, will be solved
qret | Angular position of arm at retraction time | known
Vfx | Ball velocity when lands (in the x-direction) | known
Tfin | Final time | Known

21

Tret | Retraction time | Unknown, will be solved
Vfy | Ball velocity when lands (y-axis) | Unknown, will be solved

∆x =

V + V0
2

t

(in x-direction) Pfx − Pix = (
r × ωcruise ×sin(

qret × 180
π

) + Vfx

2

) × (Tfin − Tret)

Pfx − (−0.095 − (r × cos (
qret × 180
π

))) = (
r × ωcruise ×sin(

qret × 180
π

) + Vfx

2

) × (Tfin − Tret)

(in y-direction) Pfy − Piy = (
r × ωcruise ×cos(

qret × 180
π

) + Vfy

2

) × (Tfin − Tret)

Pfy − (0.095 + (r × sin (
qret × 180
π

))) = (
r × ωcruise ×cos(

qret × 180
π

) + Vfy

2

) × (Tfin − Tret)

V

2 = V0

2 + 2a∆d

(in x-direction) Vfx = Vix due to 0 air resistance assumption

0 = 2 × ((r × aret) × sin (

| qret × 180 π )) × (Pfx − Pix)

(in y-direction) Vfy

2

– ((r × ωcruise) × cos (
qret × 180
π

))

2
=

2 × ((r × aret) × cos (
qret × 180
π

) − 9.81) × (Pfy − Piy)

22

## Contributions

Member Name | Contribution
Darwin | • Integrated Mechanical System with the Electrical Systeminto the Simulink model. • Created Simulink Model • Obtained Simulink model parameter displays into Matlab function • Research of integration techniques of Robotic Throwing Arm • Report Writing, Editing
Chad | • New motor selection and integration • New motor controller selection and integration • Tuning of the Simulink cascade controllers (current, speed, and position) • Researched local suppliers for materials • Manufacturing methods • Innovative and creative design section
Sepehr Rezvani | • Hand calculations based on selected kinematic formulas • Coding practice.m function and main.m script • Report: - Abstract - Solving Input Parameters Based on Desired Landing Position - Landing Position Testing

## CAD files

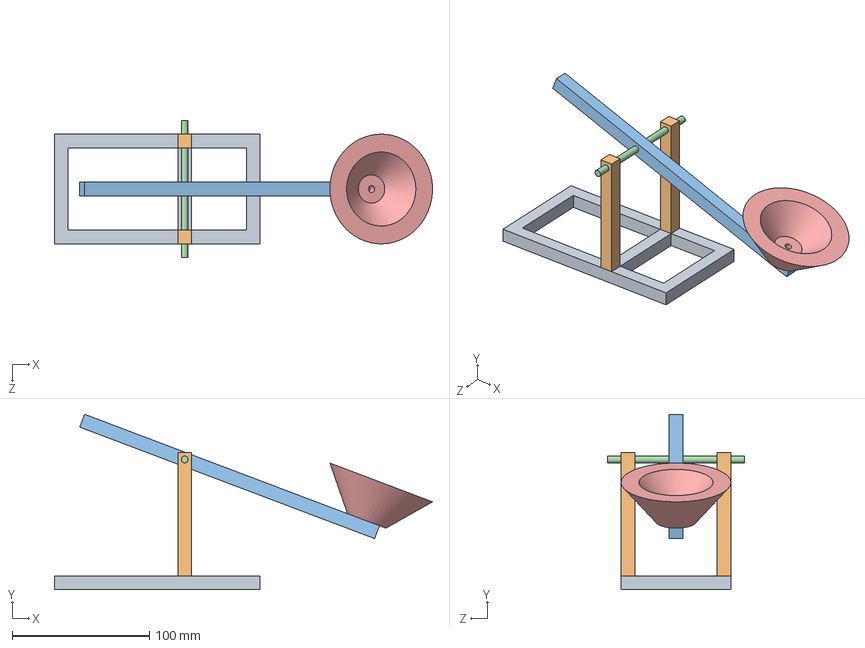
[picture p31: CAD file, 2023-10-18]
Integration/Tuned/Entire Design/throwingarmproject.SLDASM
275.7 x 128.0 x 100.0 mm
frame
link x 2
beam
uppershaft
cup

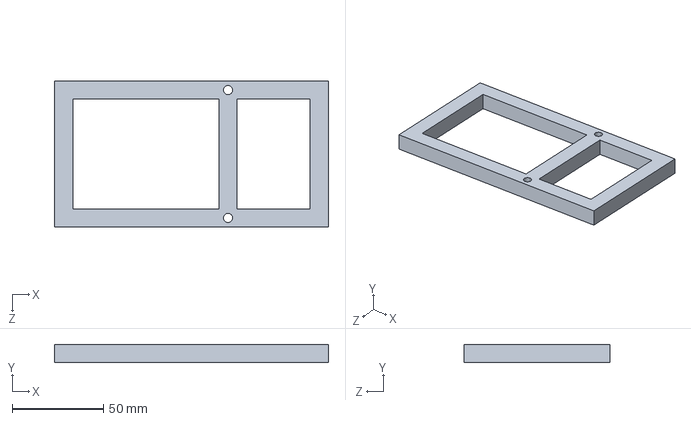
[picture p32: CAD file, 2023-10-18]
Electronics:Control/Simulation/frame_Default_sldprt.STEP
150.0 x 10.0 x 80.0 mm

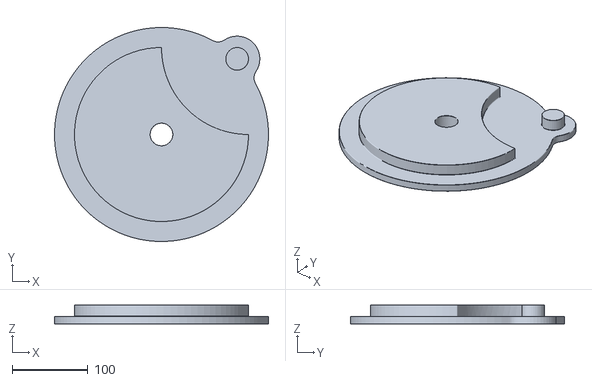
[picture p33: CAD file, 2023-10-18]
Integration/Tuned/Entire Design/Contact Forces Library/Examples/2D/Geneva_Drive/CAD/Geometry/Drive_Wheel_Default_sldprt.STL
282.8 x 282.8 x 25.0

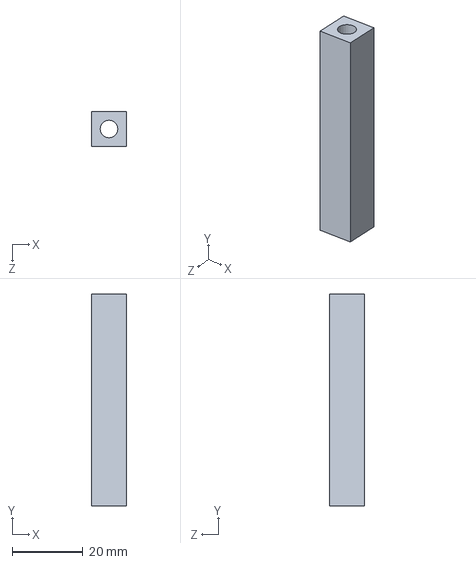
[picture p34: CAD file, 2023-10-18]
Integration/Updated_Solidworks/upperbeamframe.SLDPRT
10.0 x 60.0 x 10.0 mm

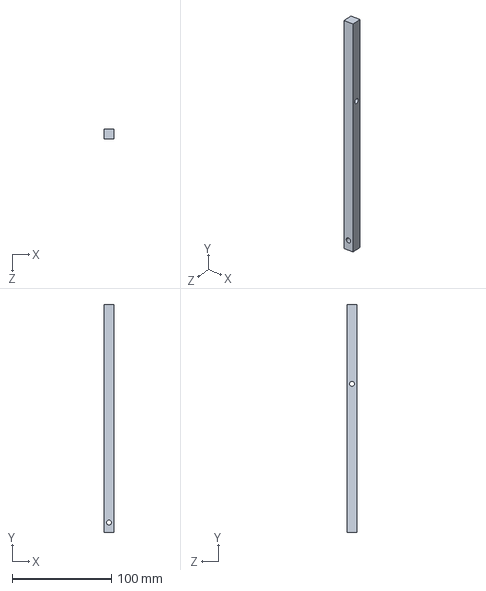
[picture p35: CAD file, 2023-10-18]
Electronics:Control/Simulation/beam_Default_sldprt.STEP
10.0 x 230.0 x 10.0 mm

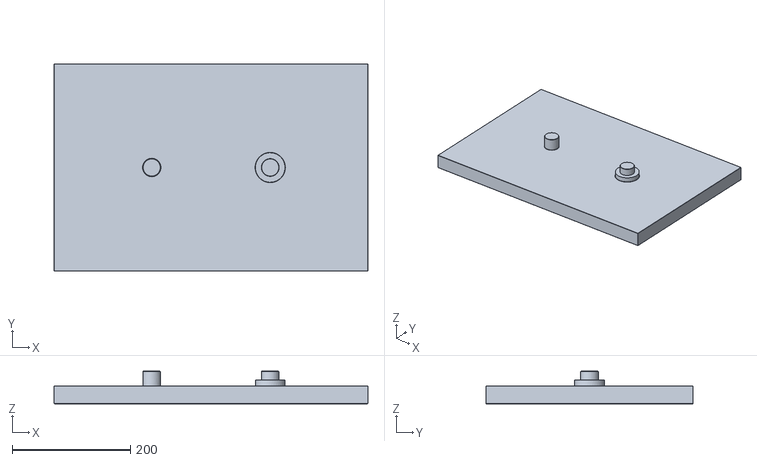
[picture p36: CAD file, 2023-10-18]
Integration/Tuned/Entire Design/Contact Forces Library/Examples/2D/Geneva_Drive/CAD/Geometry/Base_Default_sldprt.STL
530.0 x 350.0 x 55.0

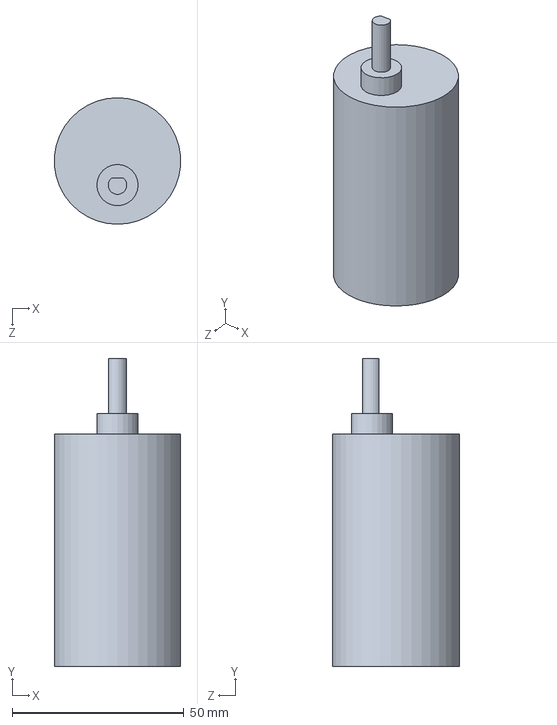
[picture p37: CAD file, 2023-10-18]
Integration/Tuned/Entire Design/Pololu Motor.SLDPRT
36.7 x 89.6 x 36.8 mm

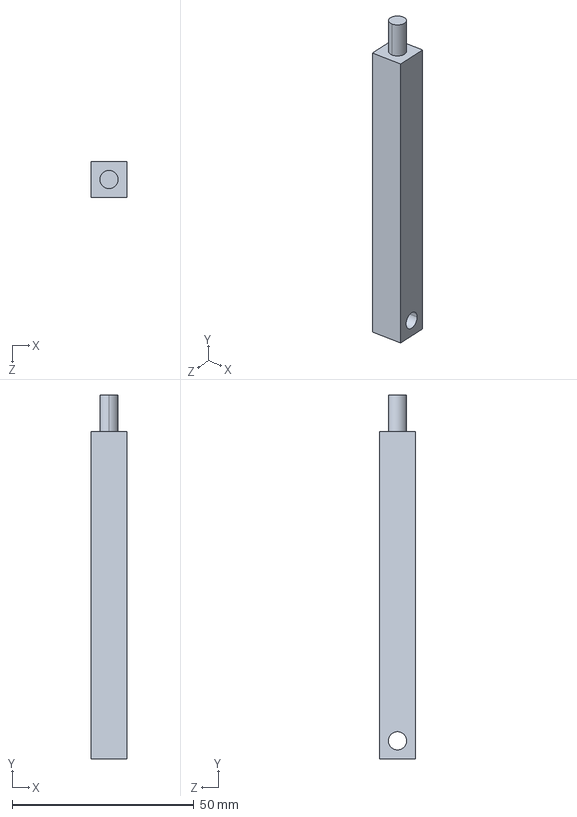
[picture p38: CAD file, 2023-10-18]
Integration/Tuned/Entire Design/link_Default_sldprt.STEP
10.0 x 100.0 x 10.0 mm

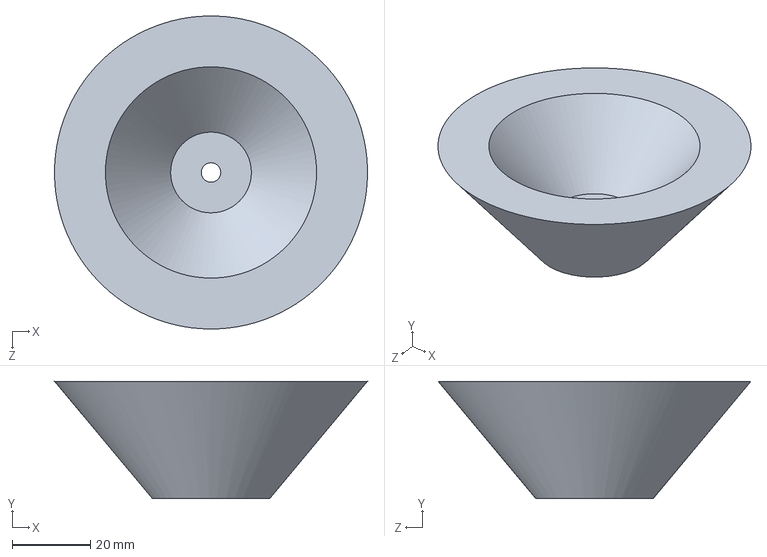
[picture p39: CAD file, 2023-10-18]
Integration/Tuned/Entire Design/cup.SLDPRT
80.0 x 30.0 x 80.0 mm

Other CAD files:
Integration/Updated_Solidworks/throwingarmproject.SLDASM
Integration/Updated_Solidworks/beam.SLDPRT
Integration/Updated_Solidworks/link.SLDPRT
Electronics:Control/Simulation/link.SLDPRT
Electronics:Control/Simulation/beam.SLDPRT
Electronics:Control/Simulation/cup_Default_sldprt.STEP
Electronics:Control/Simulation/frame.SLDPRT
Electronics:Control/Simulation/uppershaft.SLDPRT
Electronics:Control/Simulation/uppershaft_Default_sldprt.STEP
Integration/Tuned/Entire Design/beam.SLDPRT
Integration/Tuned/Entire Design/cup_Default_sldprt.STEP
Integration/Tuned/Entire Design/frame.SLDPRT
Integration/Tuned/Entire Design/link.SLDPRT
Integration/Tuned/Entire Design/uppershaft.SLDPRT
Integration/Tuned/Entire Design/uppershaft_Default_sldprt.STEP
Integration/Updated_Solidworks/cup.SLDPRT
Integration/Updated_Solidworks/cup_Default_sldprt.STEP
Integration/Updated_Solidworks/frame.SLDPRT
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

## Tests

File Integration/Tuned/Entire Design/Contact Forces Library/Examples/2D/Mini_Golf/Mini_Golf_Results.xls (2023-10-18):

Hole | Strokes | Time
1 | 3 | 33.72
2 | 3 | 32.19
3 | 5 | 59.18
4 | 3 | 39.01
5 | 3 | 34.67
6 | 3 | 40.86
7 | 4 | 41.27
8 | 4 | 45.28
9 | 3 | 27.70
Total | 31 | 353.88

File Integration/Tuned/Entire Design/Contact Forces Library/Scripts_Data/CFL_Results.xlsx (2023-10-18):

 | Contact Forces Tests | 9.10.0.1602886 (R2021a) |  |  | 07-Mar-2021 00:34:57 |  | CFL v5.0
 |  |  | Linear, No Friction |  | Linear, Stick-Slip C |  | Nonlin., No Friction |  | Nonlin., Stick-Slip C
# | Model | Stop Time | # Steps | Sim Time | # Steps | Sim Time | # Steps | Sim Time | # Steps | Sim Time
1 | Collision_01_Ball_Infinite_Plane | 6.00 | 2401 | 0.188 | 2401 | 0.131 | 2401 | 0.131 | 2401 | 0.125
2 | Collision_02_Disk_Finite_Plane_Fixed | 4.00 | 669 | 0.102 | 935 | 0.077 | 718 | 0.064 | 1008 | 0.083
3 | Collision_03_Disk_Finite_Plane_Spin | 1.50 | 298 | 0.075 | 366 | 0.044 | 317 | 0.038 | 400 | 0.046
4 | Collision_04_Disks_in_Box | 3.00 | 3765 | 1750.00 | 4749 | 2311.00 | 5071 | 2425.00 | 6035 | 3118.00
5 | Collision_05_Disk_in_Ring | 5.00 | 2052 | 0.207 | 2639 | 0.224 | 2285 | 0.208 | 2949 | 0.412
6 | Collision_06_Catapult | 1.20 | 604 | 0.163 | 582 | 0.108 | 665 | 0.112 | 484 | 0.094
7 | Collision_07_Ball_Finite_Plane_Float | 1.50 | 210 | 0.067 | 213 | 0.034 | 222 | 0.034 | 225 | 0.035
8 | Collision_08_Compare_Forces | 5.00 | 9430 | 2114.00 | 18796 | 4596.00 | 11385 | 2847.00 | 20520 | 5525.00
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

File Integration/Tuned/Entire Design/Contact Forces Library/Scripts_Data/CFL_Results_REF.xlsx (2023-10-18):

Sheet: R16b_v3p6
 | Contact Forces Tests | 9.1.0.441655 (R2016b) |  |  | 2017-02-23 13:20 |  | CFL v3.6
 |  |  | Linear, No Friction |  | Linear, Stick-Slip C |  | Nonlin., No Friction |  | Nonlin., Stick-Slip C
# | Model | Stop Time | # Steps | Sim Time | # Steps | Sim Time | # Steps | Sim Time | # Steps | Sim Time
1 | Collision_01_Ball_Infinite_Plane | 6.00 | 2400 | 2.36 | 2400 | 0.20 | 2400 | 0.20 | 2400 | 0.18
2 | Collision_02_Disk_Finite_Plane_Fixed | 4.00 | 674 | 0.41 | 959 | 0.08 | 731 | 0.07 | 1028 | 0.09
3 | Collision_03_Disk_Finite_Plane_Spin | 1.50 | 311 | 0.15 | 366 | 0.06 | 317 | 0.05 | 397 | 0.06
4 | Collision_04_Disks_in_Box | 3.00 | 3805 | 1.99 | 4277 | 2.39 | 4676 | 2.84 | 6400 | 4.15
5 | Collision_05_Disk_in_Ring | 5.00 | 2040 | 0.22 | 2678 | 0.34 | 2284 | 0.20 | 2932 | 0.31
6 | Collision_06_Catapult | 1.20 | 616 | 0.15 | 607 | 0.13 | 745 | 0.12 | 672 | 0.13
7 | Collision_07_Ball_Finite_Plane_Float | 1.50 | 200 | 0.05 | 207 | 0.03 | 213 | 0.03 | 221 | 0.03
8 | Collision_08_Compare_Forces | 5.00 | 10055 | 3.04 | 18563 | 7.24 | 12458 | 5.02 | 20798 | 7.86
9 | Friction_01_Box_on_Ramp_Constraint | 10.00 | 1211 | 0.16 | 1211 | 0.09 | 1211 | 0.09 | 1211 | 0.09
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
